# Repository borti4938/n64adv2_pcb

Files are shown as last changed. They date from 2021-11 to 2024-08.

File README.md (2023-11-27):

N64 Advanced 2 (PCB)
---

This repository contains all you need files to build your own DIY N64 Advanced board.
Firmware is supplied in another repository.

Please don't ask me for selling a modding.
I either sell some prototypes on some forums marketplaces (which is very unlikely) or I don't have any of the boards.
This is a complete DIY modding project.
Everybody is on his own here.

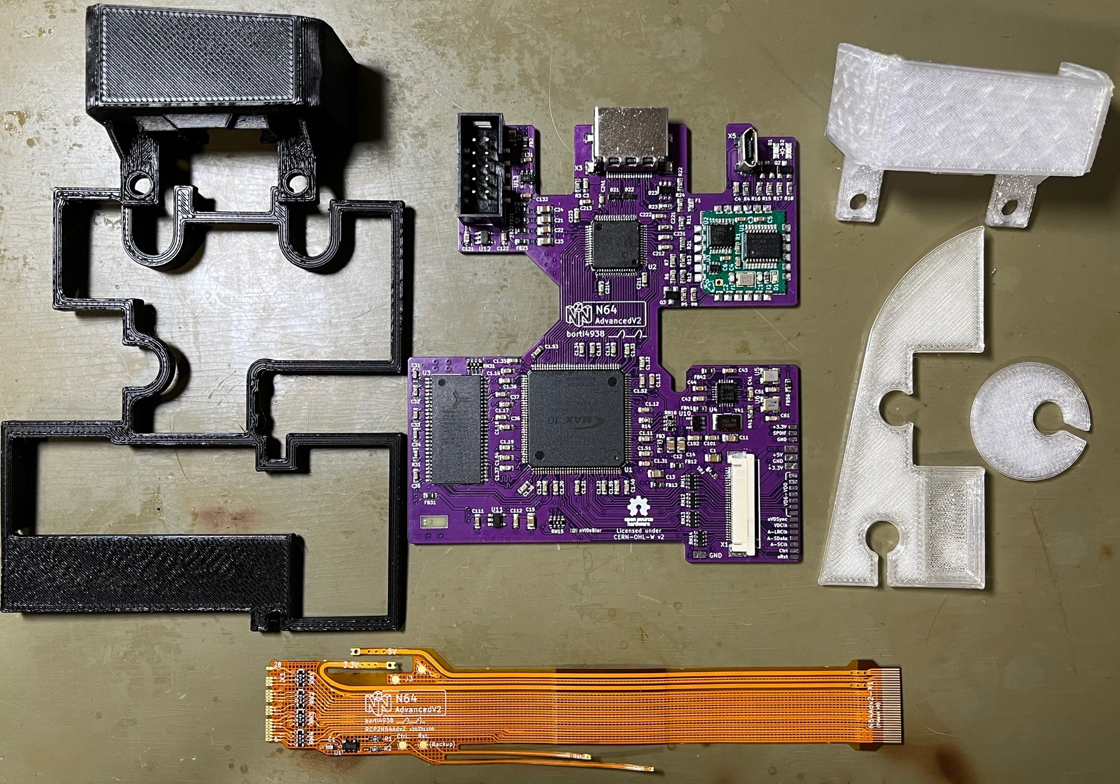
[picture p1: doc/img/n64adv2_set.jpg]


**WARNING:**
This is an advanced DIY project if you do everything on your own.
You need decent soldering skills.
The FPGA ad Video transmitter have 0.5mm fine pitch with 144pins and 64pins, respectively, and each has an exposed pad below the IC, which has to be soldered to the PCB.
Furthermore, the clocking chip is in a 24-QFN package where the pins are partwise below the IC.
It also has an exposed pad.
Next to it on the board there are some SMD1206 resistor and ferrite bead arrays.

One note on KiCad: please do not use version 7 and stay with version 6.xx.yy, if you want to edit the PCB.
I have to adapt the design files first before there are working as intended in version 7.
Thanks!

## Table of Contents

- [Checklist](https://github.com/borti4938/n64adv2_pcb#checklist-how-to-build-the-project)
- [Assembly](https://github.com/borti4938/n64adv2_pcb#assembly)
- [PCB Specs](https://github.com/borti4938/n64adv2_pcb#pcb-specs)
- [Installation](https://github.com/borti4938/n64adv2_pcb#installation)
  - [1. Open the Console](https://github.com/borti4938/n64adv2_pcb#1-open-the-console)
  - [2. Preparation](https://github.com/borti4938/n64adv2_pcb#2-preparation)
  - [3. Solder Work](https://github.com/borti4938/n64adv2_pcb#3-solder-work)
  - [4. Testing Installtion](https://github.com/borti4938/n64adv2_pcb#4-testing-installation)
  - [5. Put Everything Together](https://github.com/borti4938/n64adv2_pcb#5-put-everything-together)
- [Installation with UltraPIF](https://github.com/borti4938/n64adv2_pcb#installation-with-ultrapif)
- [Jumper Description](https://github.com/borti4938/n64adv2_pcb#jumper-description)

## Checklist: How to build the project

- Use PCB files to order your PCBs. You need the order the main PCB. If you plan to have a clean install, you need to order a flexible PCB, too. You can opt for a fully custom flex-PCB or a partial flex-PCB where you run a FFC cable from flex to main PCB. Important PCB specifications are provided in the [BOM](./doc/n64adv2_BOM.xlsx).
  - Main PCB: either [KiCAD-PCB design file](./pcbs/main/n64adv2.kicad_pcb) or [Gerber files](./gerber/main/)
  - Full Flex PCB: either [KiCAD-PCB design file](./pcbs/flex/rcp2n64adv2.kicad_pcb) or [Gerber files](./gerber/full_flex/)
  - Partial Flex PCB: either [EAGLE-PCB design file](./pcbs/flex/rcp2fpc_v5.brd) or [Gerber files](./gerber/part_flex/)
- If you plan to use solder paste, do not forget to order a stencil for top and bottom, too
- Source the components you need, e.g. from Mouser or Digikey.
  The BOM is available in [here](./doc/n64adv2_BOM.xlsx).
- If you want to use a assembly service (PCBA), you have to generate position files and BOM (in format as the fab requests it) out of the PCB design files. For JLCPCB e.g., there is a [KiCad plugin](https://github.com/Bouni/kicad-jlcpcb-tools) available (which I yet didn't test).
- Wait for everything to arrive
- Assemble your PCB if you haven't use a PCBA service
- Flash the firmware ([firmware releases](https://github.com/borti4938/n64adv2_fw/releases)) after installing:
  - Use the POF programming file named n64adv2\__fpga-device_.pof
  - Using the intelFPGA programmer, JTAG chain is initialized by loading POF file
  - Select CFM0 and UFM for program and verify
  - N64 needs to be powered for flashing
  - Power cycle the N64 after flashing

## PCB Specs

- **Main-PCB** Use PCB files (either [KiCAD-PCB design file](./pcbs/main/n64adv2.kicad_pcb) or [Gerber files](./gerber/main/)) to order your own PCB with following specs (might be not comprehensive)  
  - Size: 89.6mm x 80.0mm
  - Layer: 4
  - FPC thickness: 1.6mm
  - Min hole size: dia 0.3mm / ring 0.6mm or lower
  - Min trace width / spacing: 0.2mm
- **Flex-PCB** Use PCB files (either [KiCAD-PCB design file](./pcbs/flex/rcp2n64adv2.kicad_pcb) or [Gerber files](./gerber/full_flex/)) to order your own PCB with following specs (might be not comprehensive)  
  - Size: 129.6mm x 25.0mm
  - Layer: 2
  - FPC thickness: 0.15mm \[1\]
  - Min hole size: dia 0.25mm / ring 0.45mm or lower
  - Min trace width / spacing: 0.2mm
  - Stiffener: PI top + bottom
  - Stiffener thickness: 0.15mm \[1\]

\[1\] You may have to vary FPC thickness and stiffener thickness depending on the prototype service you are going with. E.g., on my last order I opted for 0.12mm PCB thickness and 0.225mm polyimide thickness.

## Assembly

If you have all components available, you can start assembly your board.
You can use the [interactive BOM](./doc/n64adv2_main_ibom.html), which helps you organizing your work.
It is just a matter of time and effort to assembly everything.

Note that the FPGA has an exposed pad, which needs a good connection.
Otherwise, the FPGA will not boot at all.
Preheat the FPGA with a hot air gun and solder the exposed pad from bottom if you do not use solder paste.
If you only have your solder iron, apply heat from bottom.
You must be patient at this point as there are large GND planes around the FPGA.
You may check the FPGA temperature with your finger on the top side (once it gets too hot to touch, you may stop for soldering for a moment).
Do the same with the other chips which have an exposed pad (U2 and U4).

If you populate X2 with the THT variant, which is the JTAG connector, please short the pins such that they are flush at the bottom side.
Otherwise, the PCB might be lifted in its position which produces unnecessary mechanical stress on PCB and HDMI connector.

Using non-clean flux (rosin based) is obviously recommended.
Even though it is "non-clean" I recommend cleaning everything afterwards (just for the visual finish).

Please double check everything for shorts once you finished your work.
Very important is that the power supply trace do not short to GND.
- 5V against GND (e.g. at input pads)
- 3.3V against GND (e.g. at input pads)
- 2.5V against GND (e.g. at C14)
- 2.5V against GND (e.g. at C15)
- 3.3V against GND (e.g. at C132)
- 1.8V against GND (e.g. at C122)

## Installation

### 1. Open the console

- Remove Jumper Pak / Expansion Pak
- Remove screws from bottom side of the console  
(needs a 4.5mm gamebit tool)
- Lift top housing
- remove inner screws as marked  
(in very last consoles made the heat sink design changed slightly)
- pull out the mainboard
- remove heat sink and RF shield
- **Hint** Now you have the chance to clean up your N64 shell

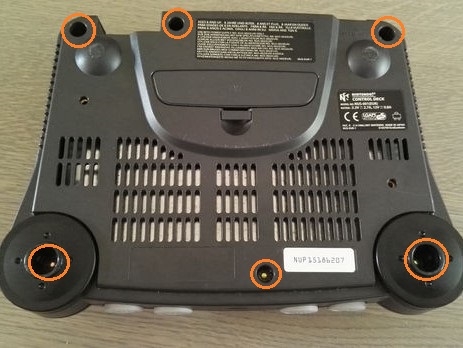
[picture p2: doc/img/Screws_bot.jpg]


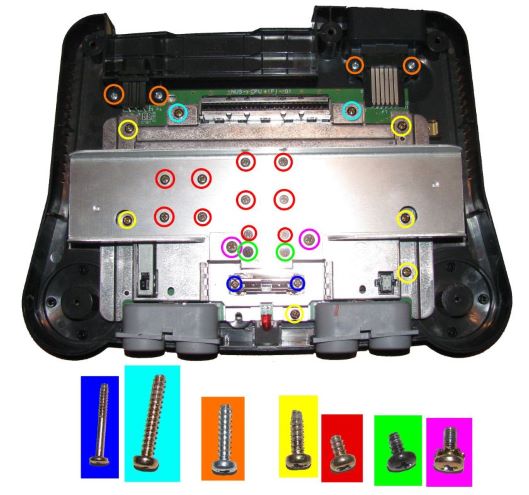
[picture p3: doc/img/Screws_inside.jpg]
  
(image by Zerberus (circuit-board.de user))

### 2. Preparation

It is possible to do a cut or a no-cut installation.
You will need the following parts for it:

1. N64Adv2 PCB
2. Flex Cable
3. Two to four of washers (M3)
4. Thermal pad
  - Cut Mod: appr. 1mm to 1.5mm thickness
  - No Cut Mod: appr. 2.5mm to 3.0mm thickness
5. 3D printed parts:
  - Cut Mod: [USB port round filler](./prints_3d/HalfCut/N64Adv2_USB_RoundFiller.stl), [JTAG spacer](./prints_3d/HalfCut/N64Adv2_JTAG_Spacer.stl) and [MultiOut replacement](./prints_3d/HalfCut/N64Adv2_MultiOut_HalfCut.stl)
  - No Cut Mod: [PCB lift bracket](./prints_3d/NoCut/N64Adv2_PCB_lift.stl) and [MultiOut replacement](./prints_3d/NoCut/N64Adv2_MultiOut_NoCut.stl)

#### 2.1 Shell Preparation Cut Mod

The bottom shell needs a cutout at the MultiOut port.

Mark the place you need to file with either the N64Adv2 PCB or the 3D printed MultiOut replacement.



File down the shell within your markings until the N64Adv2 sits flush on the shell floor.
Consider a tiny space below the HDMI connector.
Cleanup the shell and place the 3D printed parts into the shell.
Make a final fit test as shown.



#### 2.2 Shell Preparation No Cut

There is no need to cut the shell at all with this variant.
All you need is to remove the bottom RF shield from the N64 mainboard.

Place all 3D printed parts and make a fitting test as shown.



### 3. Solder Work

You have the options to either install everything with casual installation wires or using flex cables.
This is just a trade-off between personal installation effort and price.
Personally, I recommend using the flex cable.
Also with the flex cable you have the option to use a fully custom flex or a partial flex which just have a FFC connector on it to run a FFC cable from N64 to N64Adv2.

The instruction shows the installation with the fully custom flex.
The partial flex installation is similar, but not shown here.
The wired installation is not shown and not documented at all! (at least for the moment)

#### 3.1 Prepare the Flex Cable

The flex cable will be routed through the RF shield.
Close to it there are some capacitors.
Gently bend the flex cable between resistors and protection area (stiffener at top and bottom) as shown.
This relaxes routing with as low stress on the flex cable as possible.

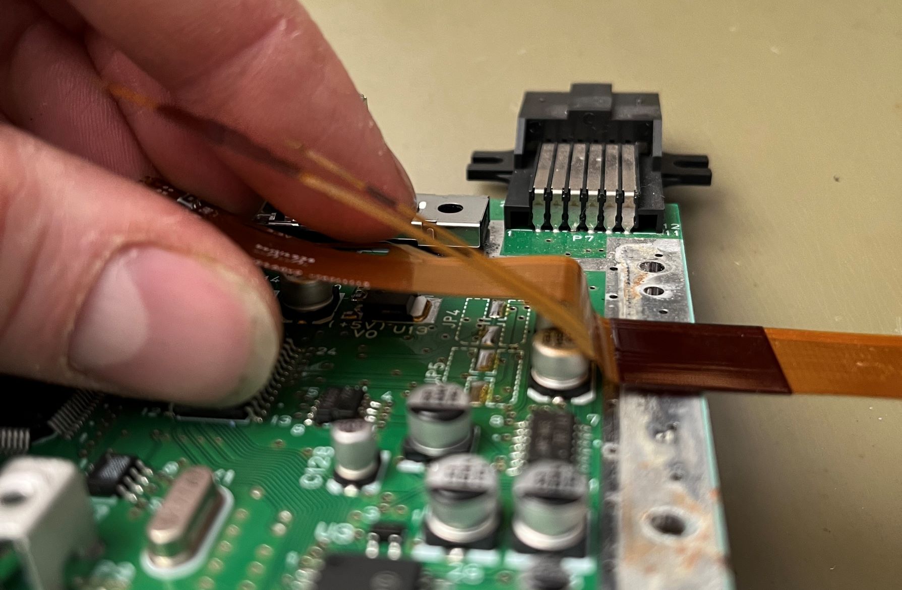
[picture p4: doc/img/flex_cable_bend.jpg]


If you opt for the partial flex, postpone this step until you have the partial flex installed (after step 3.2).
Measure where the FFC cable needs to be bend.
Apply some insulation tape for cable protection behind the bending area.

#### 3.2 Flex Cable Installation

Place the flex cable to the RCP-NUS output pins 6 to 28 as shown.
Put the solder area on to of the pins.
(However, putting them in front is also possible.)

Secure the cable with some kapton tape or with two solder joints.
Make sure that solder pads and pins are perfectly aligned.
The better the alignment is the easier is the solder work.

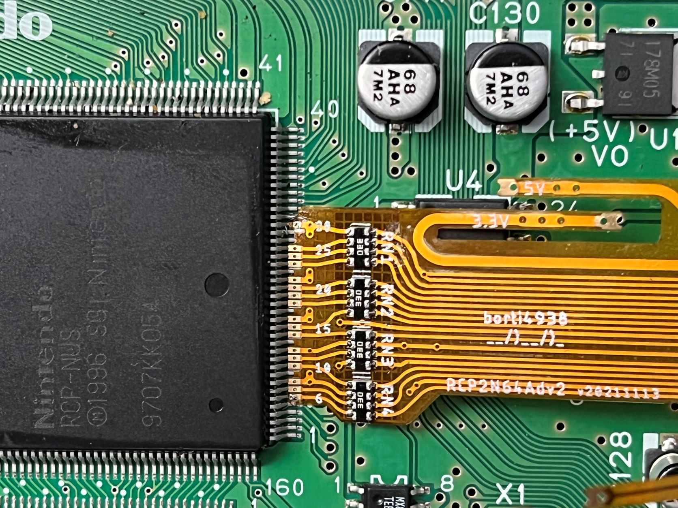
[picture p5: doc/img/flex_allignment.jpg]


Apply solder to all pins.
Double check for shorts and good connections with a continuity tester of a digital multimeter.

Solder 3.3V, 5V, Reset and Controller legs to the N64 as shown.

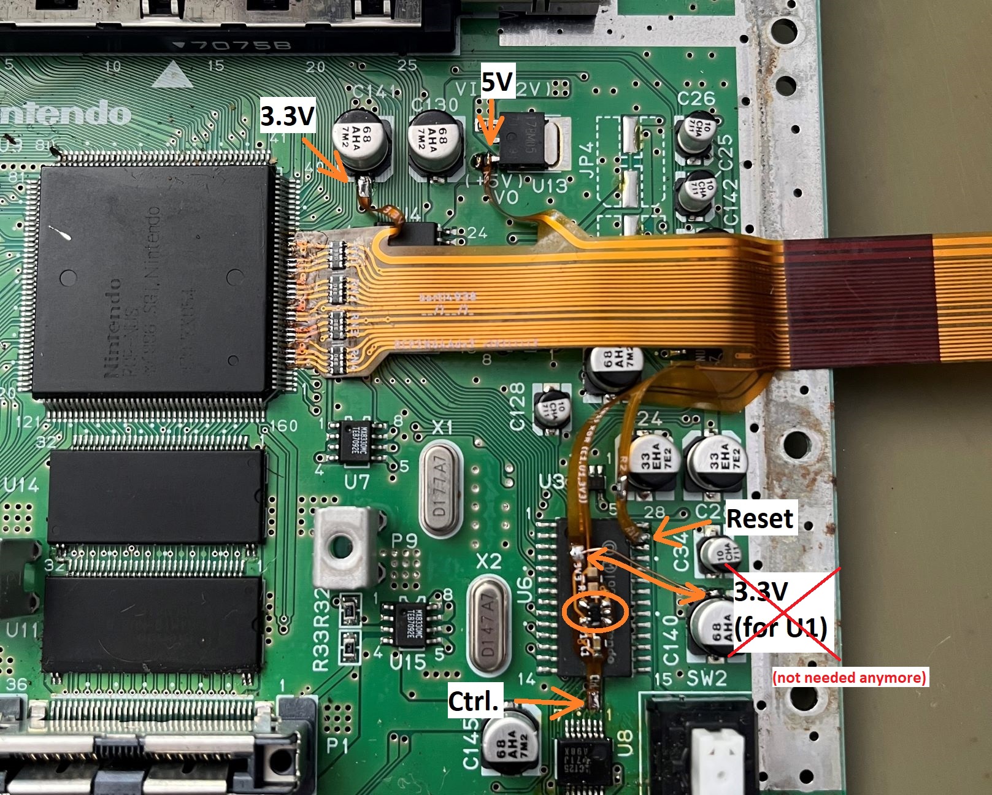
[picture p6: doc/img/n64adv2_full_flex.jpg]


Short summary:
- Solder the RCP connector side to the RCP-NUS as shown
  - first pin bottom – 6
  - last pin to – 28
- Connect 3.3V to the flex, e.g. taken from C141
- Connect 5V to the flex, e.g. taken from U13
- Connect Ctrl. and reset
  - reset from PIF-NUS pin 27
  - Controller from PIF-NUS pin 16  
  (Make sure that PIF-NUS pin 16 is connected to the middle pin of controller port 1, otherwise search for a suitable connection point)
- If you have a CPLD-based RGB mod, you can use J3 to setup VI-DeBlur on that mod over the N64Adv2
  - J3 has two pads: the left one (directly above the N64Adv2 logo) is the feedback signal, the other one is GND.
    Use a DMM if you are unsure (the GND pad has connection to any GND point on the N64 mainboard if flex is installed)
  - J3 signal pad is high on VI-DeBlur disabled and goes low if enabled

#### 3.2a Flex Cable Version 20231105 (and later)

With Version 20231105 the flex cable was redesigned at the ends to controller and reset connection at the PIF-NUS.

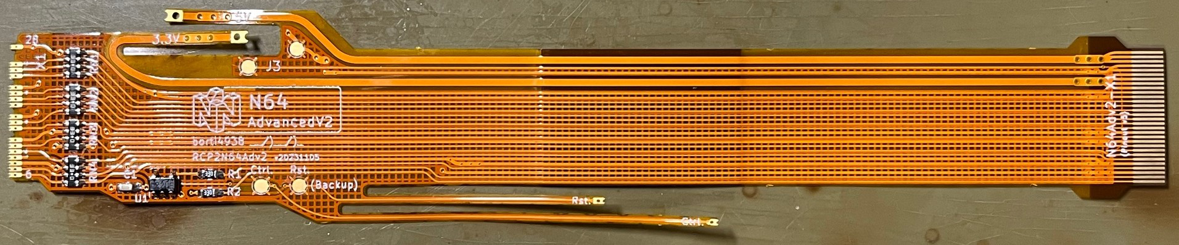
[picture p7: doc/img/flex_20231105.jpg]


Changes were:
- No components anymore on the thin cable ends for easier handling
- Using a single gate buffer (U1) for the controller line is now mandatory.
- Backup pads for controller and reset connection of the thin cable breaks.
  If cable breaks you can simply cut off the broken cable end and route a separate wire from PIF pin to the backup pad.

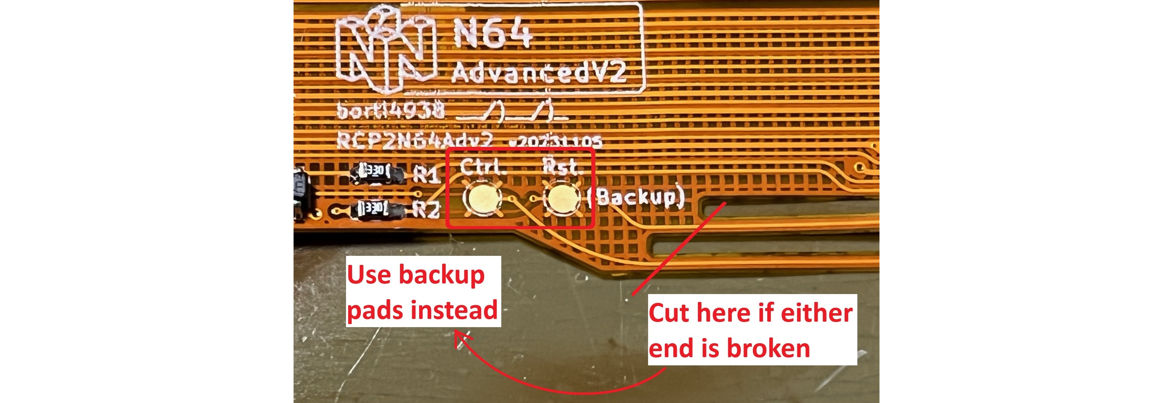
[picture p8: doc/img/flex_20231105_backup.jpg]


#### 4. Testing Installation

At this point it is a good idea to test your installtion.

First you should check for some obvious short at the power rails, e.g. between 3.3V and GND, and between 5V and GND.
If the N64Adv2 board is connected with the flex, you can simply use the input pads on the N64Adv2 board.

Insert a game cartridge, connect HDMI and power, and turn on your N64!
**Important:** If you do not have heatsinks attached to your N64, only test for a brief moment.

Obviously, the firmware of the N64Adv2 must be flashed to the FPGA.

If you see a picture with game output and here some game audio, then everything might be ok.
It's a good idea to run the debug-screen for a quick check.
If something is not ok, the N64Adv2 hardware should boot into the debug screen by default.
Then you have to go for debugging your installation.

Additional information on flashing the firmware and how to debug with the debug screen, can be found the [firmwares repository](https://github.com/borti4938/n64adv2_fw).

#### 5. Put Everything Together

Secure your installation from shorts to the top RF shield with some insulation tape.
There is a risk for shorts where the controller leg of the full flex is routed.
Everything else is safe.

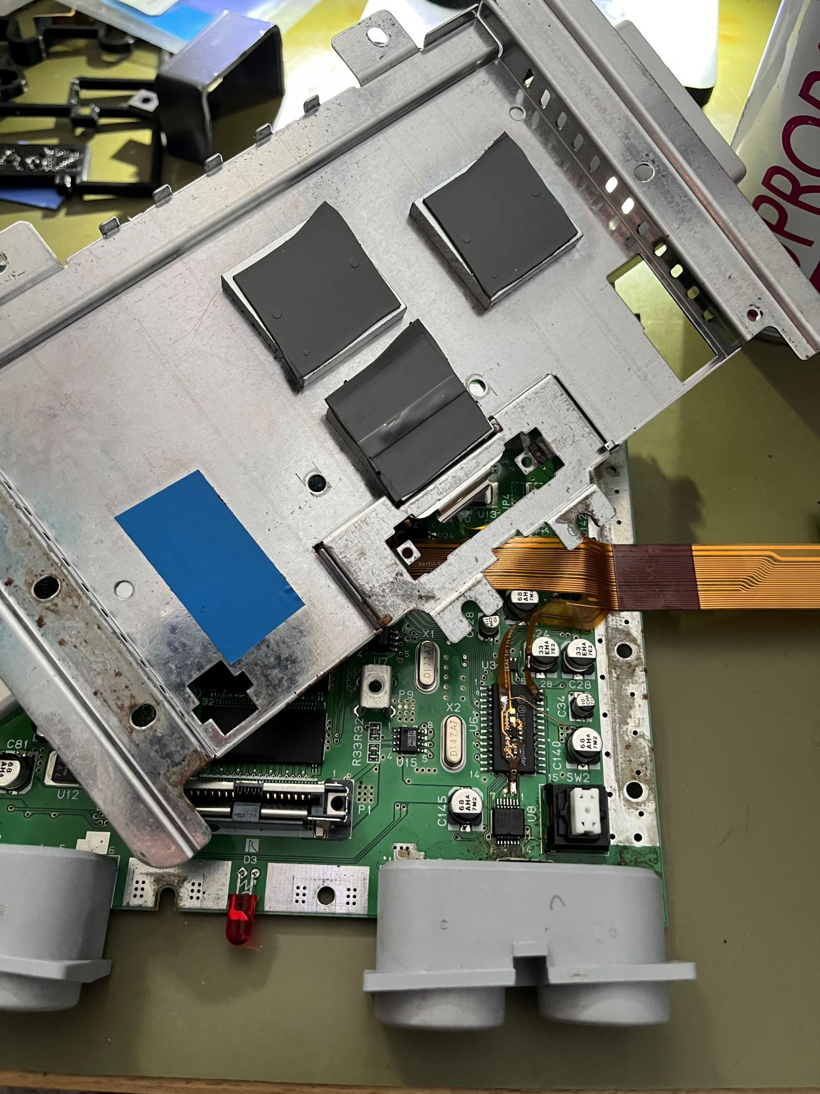
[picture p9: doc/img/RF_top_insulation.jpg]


Place some washer (about 0.5mm to 1mm height) at the screw spots left and right of the N64Adv2 flex cable.
From my experience it is easier to secure them with some tape.
Close the RF shield of the N64 then.

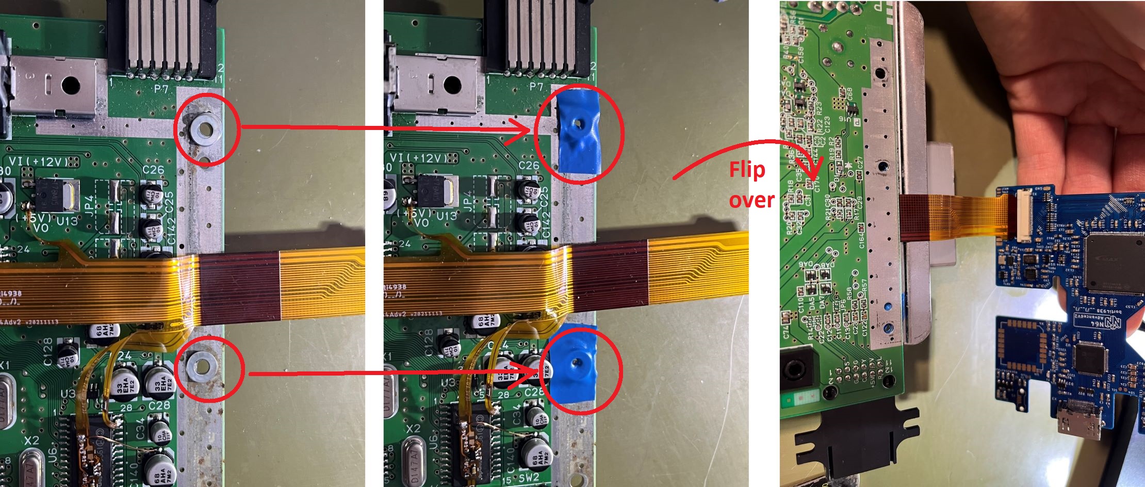
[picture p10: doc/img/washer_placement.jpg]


Now connect the N64Adv2 PCB to the flex cable.
For the Cut-Mod, also place the bottom RF shield into its place of the N64.
The RF shield does not fit in the no-cut mod variant.

Put the thermal pad on top of the FPGA (U1) of the N64Adv2 board.
This helps with heat dissipation and holds the PCB in its place.

Put everything in the bottom shell.
Do not forget 3D printings.

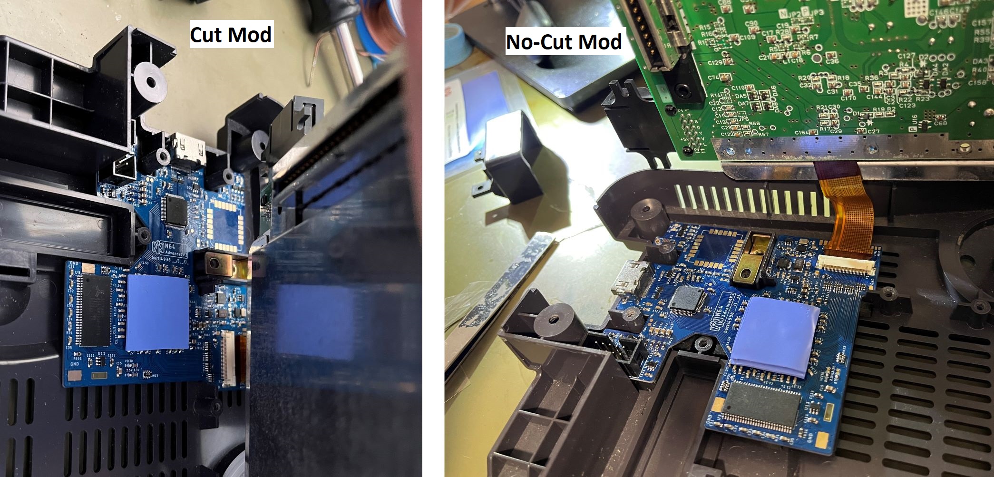
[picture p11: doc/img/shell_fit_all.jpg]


Secure the N64 with two or three screws and make a small test to see if everything is working.
Do not forget to put in the Jumper Pak or Expansion Pak, otherwise you won't see a picture at all.

If everything works fine, close the whole shell.

## Installation with UltraPIF

This guide assumes that the UltraPIF will be installed after the N64Adv2.
However, other installation orders are possible, too - i.e. UltraPIF first and then N64Adv2 or both alongside.
There are not described, here.
For the ease of debugging, installation one after the other is always recommended.

Also, it is not described, how to open and close the N64.

### 1. Remove PIF-NUS

To remove the PIF-NUS, remove reset and controller connections, first.

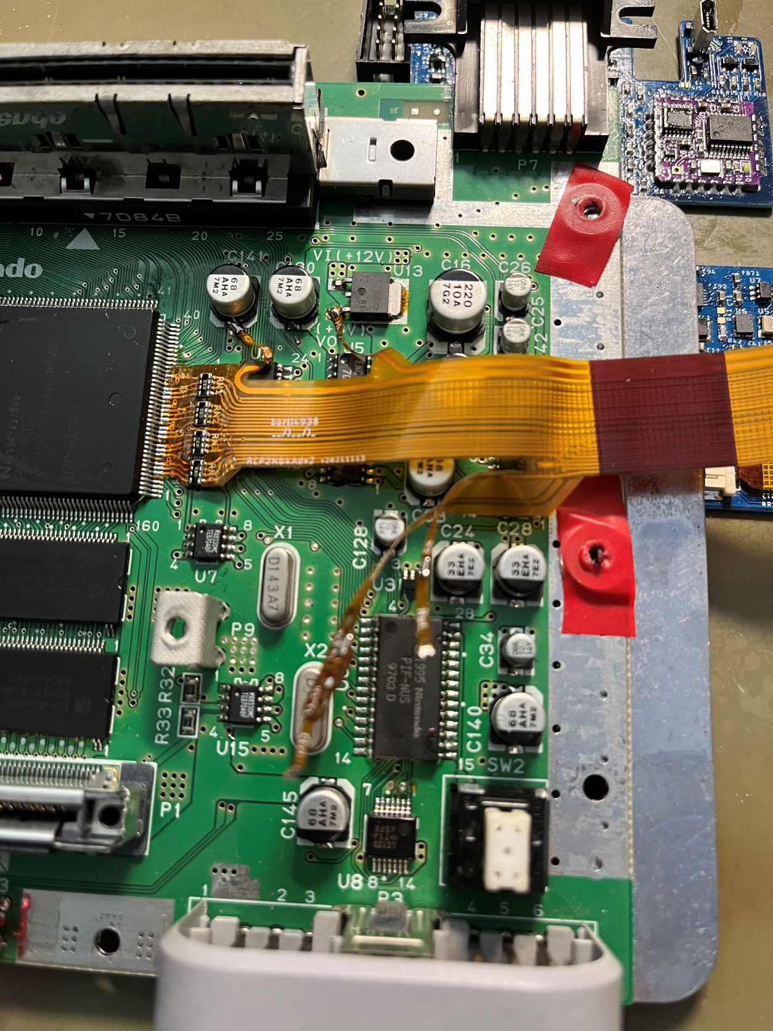
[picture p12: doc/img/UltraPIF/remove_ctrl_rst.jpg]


The remove the PIF-NUS.

### 2. Install UltraPIF Adapter Board

Put the UltraPIF board into its place.
Connect clock and mode wires and if you want, the RGB led board.
More details on that can be found in the [UltraPIF Repository](https://github.com/jago85/UltraPIF_Hardware/wiki/Installation).

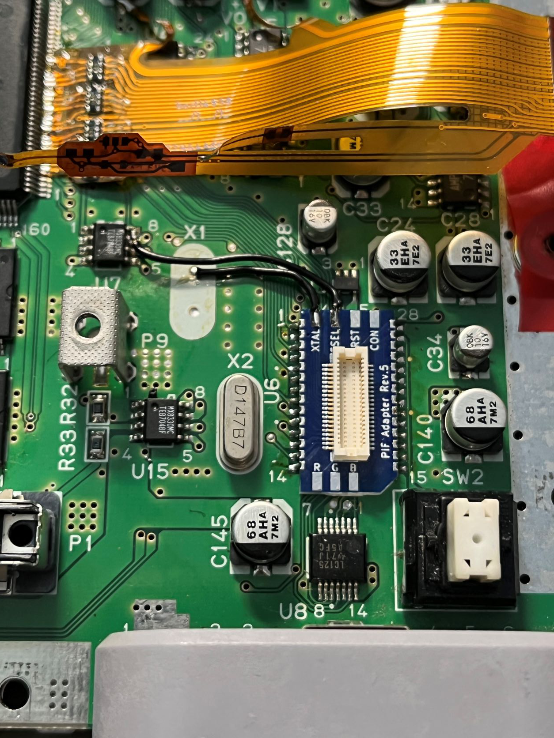
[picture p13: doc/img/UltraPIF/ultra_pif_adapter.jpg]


### 3. Connect Flex Cable

Once the UltraPIF Adapter sits in its place, you can reconnect the reset and controller connections of the flex cable.

For the controller connection, you can use the _CON_ pad on the adapter.

For the reset connection you have to go for pin 27 on the adapter.
**DO NOT USE THE _RST_ PAD!** as it acts as an input only.
Fallback functions won't be available if you do so.
Check the connection for shorts to adjacent pins.

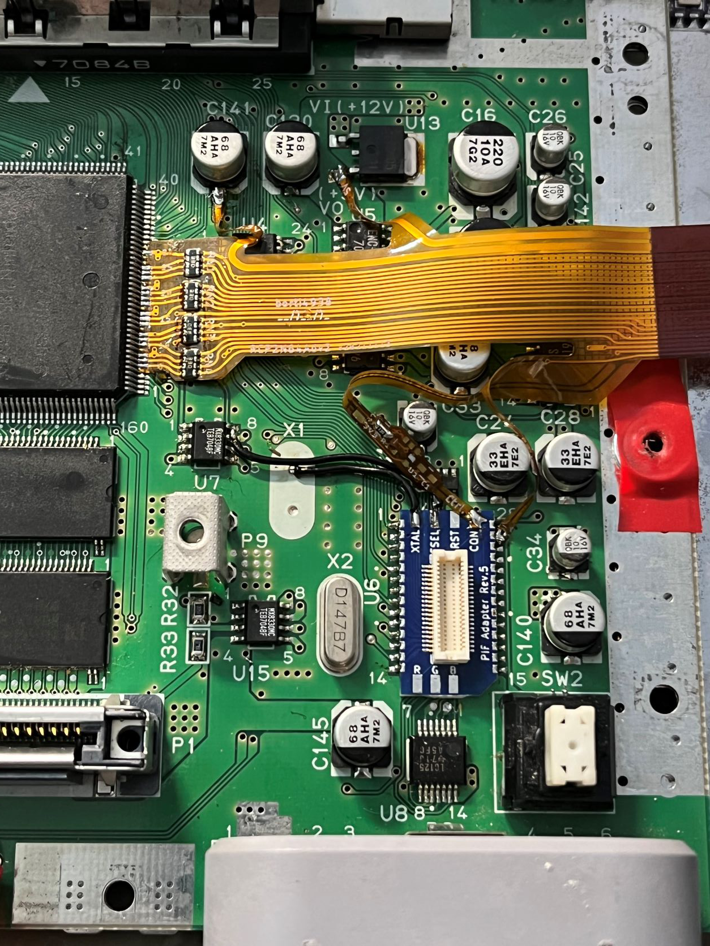
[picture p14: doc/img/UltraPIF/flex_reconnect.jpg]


### 4. Done

Put the UltraPIF on the UltraPIF Adapter board.

## Jumper Description

**IMPORTANT NOTE**  
Most jumpers are for development reasons and do not need to be touched at all.
This section is only for documentation purposes.

### On main N64Adv2 PCB

##### SJ1 to SJ4 (IO power supply for FPGA Bank 6 and 7)

**Section is outdated. Jumpers had been removed with version 20231119**

Bank B6 and B7 needs 2.5V VCCIO for current implementation.
Since N64Adv2_202200415, these jumpers are closed by default at 2.5V.
Earlier prototypes need a solder joint at 2.5V.
Do not touch 3.3V jumper as current implementation runs IO speed over specifications then.

##### SJ5 (5V power via USB port (X5))

**Section is outdated. Jumper has been removed with version 20231119**

- opened: (default) disable 5V power via USB
- closed: enable 5V power via USB

##### SJ6 (3.3V power via JTAG programmer X4)

**Section is outdated. Jumper has been removed with version 20231119**

- opened: (default) disable 3.3V power via JTAG programmer
- closed: enable 3.3V power via JTAG programmer

#### SJ11 (VI-DeBlur feedback)
- opened: disable feedback for fir flex prototypes
- closed: (default by a trace) feedback enabled

##### SJ31 (SRAM A12)

**Section is outdated. Jumper has been removed with version 20231119**

- opened: (default) use 8Mx16 memory
- closed: use 16Mx16 memory (firmware needs adaptation to work with 16Mx16 memory)

### On flex PCB

##### SJ1

**Section is outdated. Jumpers had been removed with version 20231105**

- opened: use with Schmitt trigger buffer (U1 and C1)
- closed: close jumper if you do not use Schmitt trigger buffer (U1 and C1)

##### J3
- VI-DeBlur feedback for CPLD based RGB mods (see installation section)

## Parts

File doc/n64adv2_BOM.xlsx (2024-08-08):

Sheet: Main
Number of PCBs |  | 3
Designator | MPN | QTY/PCB | QTY | DESCRIPTION | VALUE | PACKAGE | NOTES | Digikey | Mouser
U1 | 10M16SAE144 | 1 | 3 | Max10 FPGA, 16k LE |  | EQFP144 | For user
 | 10M25SAE144 |  |  | Max10 FPGA, 25k LE |  | EQFP144 | For developer or as user alternative (more FPGA resources)
U2 | ADV7513BSWZ | 1 | 3 | HDMI Transmitter | ADV7513 | 48-LQFP | Aliexpress
U3 | AS4C8M16SA-xTCN | 1 | 3 | SDRAM Speicher-IC 128 Mb (8 M x 16) Parallel |  | TSOP-54 | x = Speedgrade (6 = 166MHz, 7 = 143MHz)
U4 | SI5356A-B-GMR | 1 | 3 | Clock generator |  | QFN-24
U5 | ECS-3225MV-500-CN-TR | 1 | 3 | OSC 50MHz for system pll |  | 4-SMD | L x B: 0,126" x 0,098" (3,20 mm x 2,50 mm)
U6 | ECS-3225MVLC-245.7-CN-TR | 1 | 3 | OSC 24.576MHz for audio |  | 4-SMD | L x B: 0,126" x 0,098" (3,20 mm x 2,50 mm)
U10 | TLV70225DBVR | 1 | 3 | LDO 2.5V, 300mA |  | SOT-23-5
U11 | TLV70025DDCR | 1 | 3 | LDO 2.5V, 200mA |  | SOT-23-5 | same as U10 can be used (but not vice versa)
 | TLV70225DBVR |  |  | Alternative for U11 (same as U10) |  | SOT-23-5
U12 | TLV70218DBVR | 1 | 3 | LDO 1.8V |  | SOT-23-5
U13 | TLV70033DDCR | 1 | 3 | LDO 3.3V |  | SOT-23-5
Y41 | 445I23D27M00000 | 1 | 3 | 27MHz crystal |  | 5.0X3.2
FB1,FB2,FB11,FB12,FB13,FB21,FB22,FB23,FB24,FB31,FB41,FB42,FB56 | MPZ1608S221A | 13 | 39 | Ferrit bead, power line |  | SMD0603
C1,C2 | ‎GRT21BR60J476ME13L‎ | 2 | 6 | Ceramic capacitor, X5R | 47uF / 6.3V | SMD0805
C11,C12,C13,C14,C15,C21,C22,C23,C24 | ‎CL21A106KPFNNNG‎ | 9 | 27 | Ceramic capacitor, X5R | 10uF / 6.3V | SMD0805
C101,C102,C111,C112,C121,C122,C131,C132 | ‎CL10A105KP8NNWC‎ | 8 | 24 | Ceramic capacitor, X5R | 1uF / 6.3V | SMD0603
C1.11,C1.12,C1.13,C1.14,C1.15,C1.16,C1.17,C1.18,C1.19,C1.20,C1.21,C1.22,C1.31,C1.32,C1.33,C1.34,C1.35,C1.36,C1.37,C1.38,C1.39,C1.40,C1.51,C1.52,C1.53,C1.54,C1.55,C3,C31,C32,C33,C34,C35,C36,C37,C41,C42,C43,C44,C211,C212,C213,C214,C221,C222,C223,C231,C241 | CL10B104KB8NNNL | 48 | 144 | Ceramic capacitor, X7R | 0.1uF / 50V | SMD0603
C51,C61 | CL10B103KB8NNNC | 2 | 6 | Ceramic capacitor, X7R | 0.01uF / 50V | SMD0603
R3 | RC0603FR-071ML | 1 | 3 | Resistor | 1M | SMD0603
R12,R13,R22 | RC0603FR-0710KL | 3 | 9 | Resistor | 10k | SMD0603
R23,R24 | RC0603FR-072KL | 2 | 6 | Resistor | 2k0 | SMD0603
R11,R15,R17,R31,R41 | RC0603FR-071KL | 5 | 15 | Resistor | 1k0 | SMD0603
R21 | RC0603FR-07887RL | 1 | 3 | Resistor | 887 | SMD0603
R16,R18 | RC0603FR-07330RL | 2 | 6 | Resistor | 330 | SMD0603
R14 | RC0603FR-0733RL | 1 | 3 | Resistor | 33 | SMD0603
RN11,RN12,RN13,RN14 | BLA31AG121SN4D | 4 | 12 | Ferrite Beads MULTILYR CHP | BD 120OHMS 25% | SMD1206
RN15,RN31 | CAY16-103J4LF | 2 | 6 | Resistor Array (4x) | 10k0 | SMD1206
RN16 | CAY16-2201F4LF | 1 | 3 | Resistor Array (4x) | 2k2 | SMD1206
F1 | MF-FSMF020X-2 | 1 | 3 | 200mA Fuse |  | SMD0603
D1 | LTST-C194KRKT | 1 | 3 | Red LED |  | SMD0805
D2 | LTST-C194KGKT | 1 | 3 | Green LED |  | SMD0805
 | LTST-C194KRKT |  |  | Alternative for D2 (same as D1) |  | SMD0805
D21,D22 | RCLAMP0524PATCT | 2 | 6 | TVS Diode |  | 10-UFDFN
 | SZESD7104MUTAG |  |  | TVS Diode |  | 10-UFDFN | Alternative
D23 | NUP4114HMR6T1G | 1 | 3 | Clamping Diode Array |  | TSOP-6
Q1,Q2 | ZXTN08400BFFTA | 2 | 6 | NPN-Transistor |  | SOT-23
X1 | 3-1734592-0 | 1 | 3 | contacts bottom, cable 0.3mm thick (flex + stiffener) |  |  | 30 pin 0.5mm flat cable connector, reverse v5 pinout, 5V & 3.3V power rail, GND and data
 |  |  |  |  |  |  | only in combination with flex (see separate tab)
X2 | 3020-10-0300-00 | 1 | 3 |  |  |  | JTAG Connector (2x5 pins in 100mil pitch; SMD)
 | 30310-6002HB |  |  | Alternative for X2 as THT, but need to short pins |  |  | JTAG Connector (2x5 pins in 100mil pitch; THT)
 |  |  |  |  |  |  | optional if onboard USB Blaster is used (see separate tab)
X3 | 2000-1-2-41-00-BK | 1 | 3 | HDMI Connector 19pin with SMD mounted shield |  |  | Full Size HDMI Connector
X4 | Onboard USB Blaster |  |  |  |  |  | see Onboard USB Blaster page

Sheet: Onboard USB Blaster
Number of PCBs |  | 3
Designator | MPN | QTY/PCB | QTY | DESCRIPTION | VALUE | PACKAGE | NOTES | Digikey | Mouser
X4 | TEI0005 | 1 | 3 | FPGA USB-Programmer2 SMD-Modul |  |  | Buy: https://shop.trenz-electronic.de/de/TEI0005-02-FPGA-USB-Programmer2-SMD-Modul-VPE1?c=26
 |  |  |  |  |  |  | Wiki: https://wiki.trenz-electronic.de/display/PD/TEI0005+-+FPGA+Programmer2+SMD
 | DIY |  |  | DIY USB Blaster module project |  |  | Thx to ikari_01 (creator sd2snes / fxpak)
X5 | USB3140-30-0170-0-C | 1 | 3 | USB-MICRO-VERTICAL-DIY
C4 |  | 1 | 3 | Ceramic capacitor, X7R | 0.1uF / 50V | SMD0603
R4 | RC0603FR-071ML | 1 | 3 | Resistor | 1M | SMD0603
R5,R8 | RC0603FR-0710KL | 2 | 6 | Resistor | 10k | SMD0603
R6,R7 |  | 2 | 6 | Resistor | 1k0 | SMD0603 | 1k to 5k
Q3 | ZXTN08400BFFTA | 1 | 3 | NPN-Transistor |  | SOT-23

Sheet: Flex
Number of PCBs |  | 3
Designator | MPN | QTY/PCB | QTY | DESCRIPTION | VALUE | PACKAGE | NOTES | Digikey | Mouser
U1 | 74LVC1G17DBV | 1 | 3 | Schmitt-Trigger Buffer |  | SOT-23-5
C1 | CL10B104KB8NNNL | 1 | 3 | Ceramic capacitor, X7R | 0.1uF / 50V | SMD0603
RN1,RN2,RN3,RN4 | CAY16-330J4LF | 4 | 12 | Resistor Array (4x) | 33ohm | SMD1206
R1,R2 | RC0603FR-0733RL | 2 | 6 | Resistor | 33ohm | SMD0603

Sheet: Jumper
Testpads | Description
SPDIF | SPDIF output, e.g. for optical audio link
+3.3V, +5V, GND | Power connection (for SPDIF, testing, whatever)
VD0 - VD6, nVDSync, VDClk, A-LRClk, A-Sdata, A-SClk, Ctrl, nRst | Pads to connect the N64Adv2 mainboard without the flex cable
 | Usefull for debugging if N64Adv2 is not working after installation with flex
Jumper on Flex | Description
J3 | Feedback signal from N64Adv2 for VI-DeBlur setting
Ctrl. (Backup) | Backup pad to route a wire from PIF to flex if trace end on flex is broken
Rst. (Backup) | Backup pad to route a wire from PIF to flex if trace end on flex is broken

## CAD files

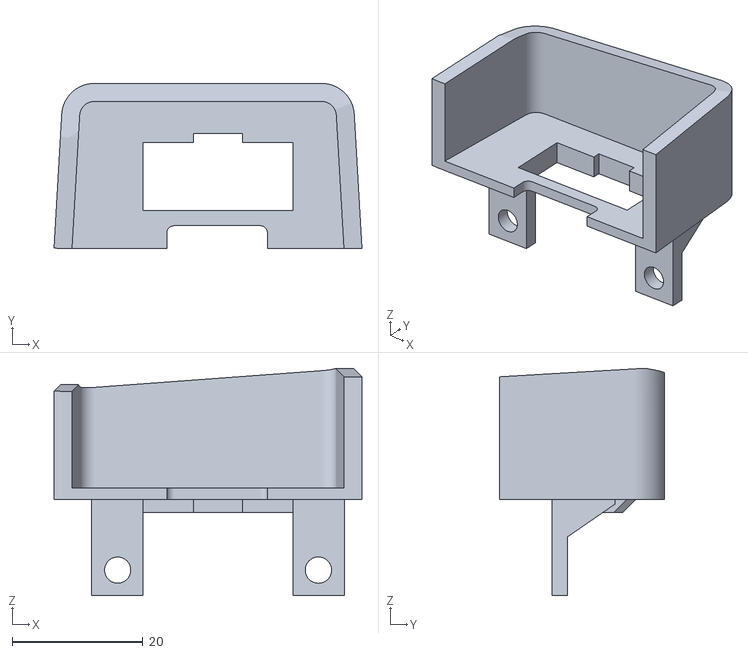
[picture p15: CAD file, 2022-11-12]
prints_3d/HalfCut/N64Adv2_MultiOut_HalfCut.stl
47.1 x 25.3 x 34.8

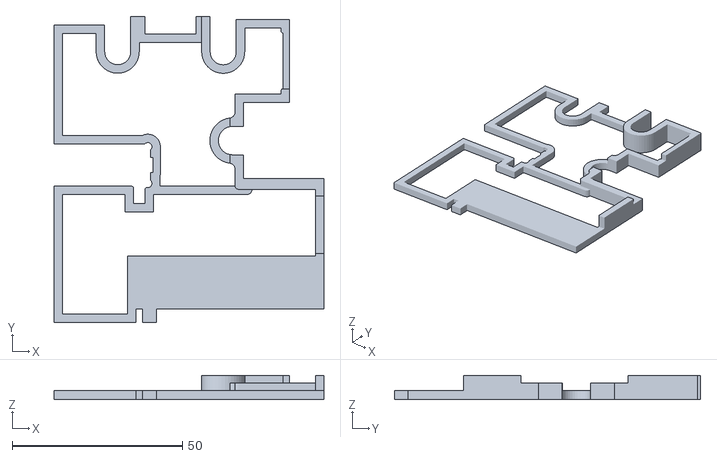
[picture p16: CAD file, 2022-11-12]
prints_3d/NoCut/N64Adv2_PCB_lift.stl
79.1 x 89.8 x 7.11

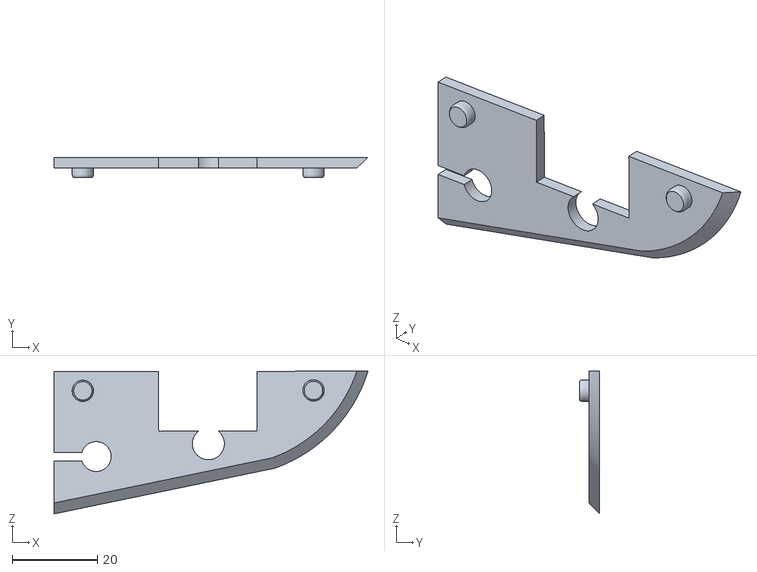
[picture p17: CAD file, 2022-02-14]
prints_3d/HalfCut/N64Adv2_JTAG_Spacer.stl
73.5 x 4.75 x 33.4

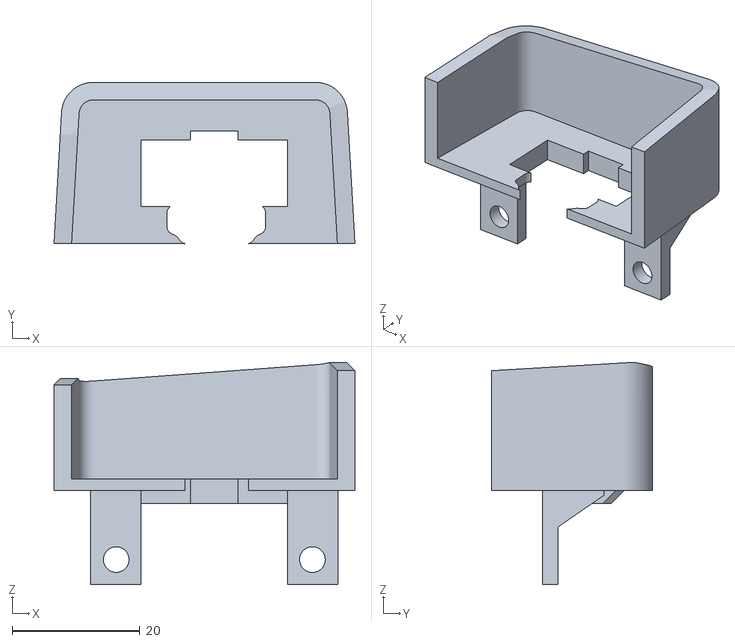
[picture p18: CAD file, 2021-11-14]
prints_3d/NoCut/N64Adv2_MultiOut_NoCut.stl
47.1 x 25.3 x 34.8

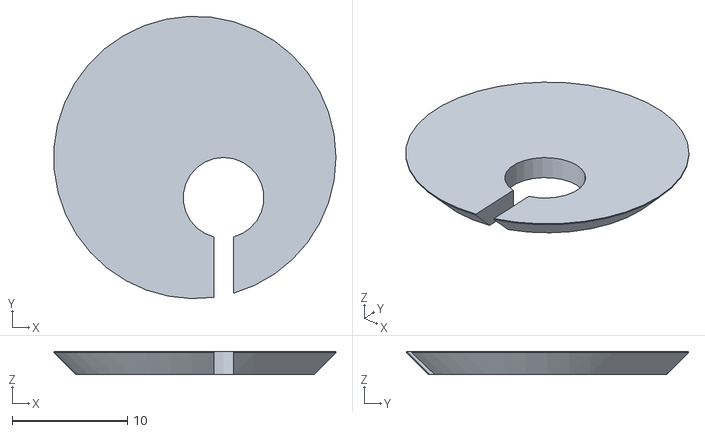
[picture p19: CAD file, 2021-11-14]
prints_3d/HalfCut/N64Adv2_USB_RoundFiller.stl
24.5 x 24.5 x 2.00

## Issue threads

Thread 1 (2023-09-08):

PCB mounting files

nrayner, 2023-09-08:
In the readme it says:

If you want to use a assembly service (PCBA), you can use the mounting files for [main](https://github.com/borti4938/n64adv2_pcb/blob/master/doc/n64adv2-top-pos.csv), full flex-PCB and/or part flex-PCB, too.

But the link doesn't work, I could not find the files anywhere else in the repository.

borti4938, 2023-09-08:
Sorry. I removed the file as it was not working for any fab. At the moment you have to generate your own files in a format as requested by the fab of your choice. Maybe we will add some example files for JLCPCB in near future.

nrayner, 2023-09-08:
Ok thanks

Closed 2024-08-25.

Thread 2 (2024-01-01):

Alternativ FPGA?

cerritus55, 2024-01-01:
Is there any alternativ for the FPGA thats still aviable and working with this project?

borti4938, 2024-01-04:
New FPGA needs a redesign of PCB and firmware. Everything is open source, so feel free to make your adaptations. Or just be patient - FPGAs will be available soon. Estimated delivery date at Digikey is 01/17/2024 if you order today.

Closed 2024-01-04.

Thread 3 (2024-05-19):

Interference

Slypty, 2024-05-19:
I've made a set of 8 N64Adv2 boards with PCBWay, received them and doing some testing.  2 of the 8 boards test well, the other 6 all have blue pixels that appear.  The pixels will go away if I press down between the FPGA MAX 10 and the Alliance IC as shown below.  I have tried touching up solder joints in this area but no differences were made.

  If I add thermal tape to the underside of the PCB it gets better.  Eventually the pixels go away after many minutes.  6 boards all have this issue, I am wondering if I should replace the caps in this area, or maybe if this is a noisy 3.3V line?  Is this a problem you're familiar with?   Hope you can help, thanks
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

Slypty, 2024-05-22:
Well it ended up being a faulty N64 Power Supply, so it can be deleted/closed.

borti4938, 2024-05-22:
Thanks for closing. I'm happy that you were able to track down the issue :)

Closed 2024-05-22.

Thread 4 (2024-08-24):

SDRAM alternative part

gmiranda, 2024-08-24:
Hi,

I'm having trouble sourcing the alliance SDRAM chip (AS4C8M16SA) and I'm looking into alternatives. I think this Winbond W9812G6KH ([datasheet](https://www.lcsc.com/datasheet/lcsc_datasheet_2304140030_Winbond-Elec-W9812G6KH-6_C62379.pdf)) would work but I'm not sure.

Could you please have a look or suggest another IC?

Thanks!

borti4938, 2024-08-25:
Hi,

the AS4C8M16SA-7TCN is available on Digikey and Mouser on high quantities at least. So it should be a problem to source the SDRAM.

For the W9812G6KH you have to go for speed rating -5 or -6. Then it should work. However, no guarantee on that as I just shortly scanned over pinout, commands and AC characteristics. But you may want to provide feedback, once tested. If you go for the chip with speed rate -75, you may have to adjust clock rate (143MHz to 133MHz), tRC (63ns -> 65ns) and tRAS (42ns -> 45ns). Otherwise it might be a bit of luck whether it works with current firmware or not.

Best regards

gmiranda, 2024-09-01:
Hi borti,

Thanks a lot for replying. I was planning on avoiding Mouser and instead go to LCSC, but now I see that I'd have to use a lot of alternative parts.

That said, I'm still having some trouble sourcing a couple of components. The first one would be U7, 74LVC2G17DBV. The closest one I can find on either Mouser or DigiKey is 74LVC2G17DBV**R**. Is it the same thing?

I also have doubts regarding the flex pcb, I hope you don't mind me asking. Have you ever ordered from JLCPCB? I don't know what to select on **Gold fingers**. Options are _yes_/_no_ and then it asks me about the gold finger thickness which puts me at a loss.

Thanks a lot!

borti4938, 2024-09-02:
Not sure, if you are using the latest version. Last version has neither U7 nor the gold fingers.

borti4938, 2024-09-02:
These are the options I set on my last order for the flex pcb. Works well
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

gmiranda, 2024-09-02:
> Not sure, if you are using the latest version. Last version has no U7. For the flex, you have to select "yes" for gold fingers (pins at the end for the connector).
It looks like I wasn't, thanks!

> These are the options I set on my last order for the flex pcb. Works well !
Awesome borti, thanks a lot! It looks like I had the values miraculously right.

gmiranda, 2024-09-04:
I'm now going through the flex pcb BOM and I'm having a similar issue with U1 as I did with former U7. Searching for 74LVC1G17DBV returns quite 6 different part numbers with the closest ones being SN74LVC1G17DBVR and SN74LVC1G17DBVT. Which one should I order?

borti4938, 2024-09-07:
You can go with either one. "SN" is probably for Texas Instrument and "R"/"T" is just the packaging the device comes (reel or tube), which is not important at all. Take the cheaper version.

gmiranda, 2024-10-22:
Sorry to keep bothering you... Are the pads of the clamps D21 and D22 intended to be electrically connected? I mean that with the bare PCB there's connection between the north side (HDMI connector) and the south side (analog devices chip) pads:

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

This lead me to believe that I had botched the solder work of these diodes :facepalm:

Once again, thanks a lot!

gmiranda, 2024-11-03:
I guess the answer is yes. I just don't understand how these clamps work.

Closed 2024-11-03.

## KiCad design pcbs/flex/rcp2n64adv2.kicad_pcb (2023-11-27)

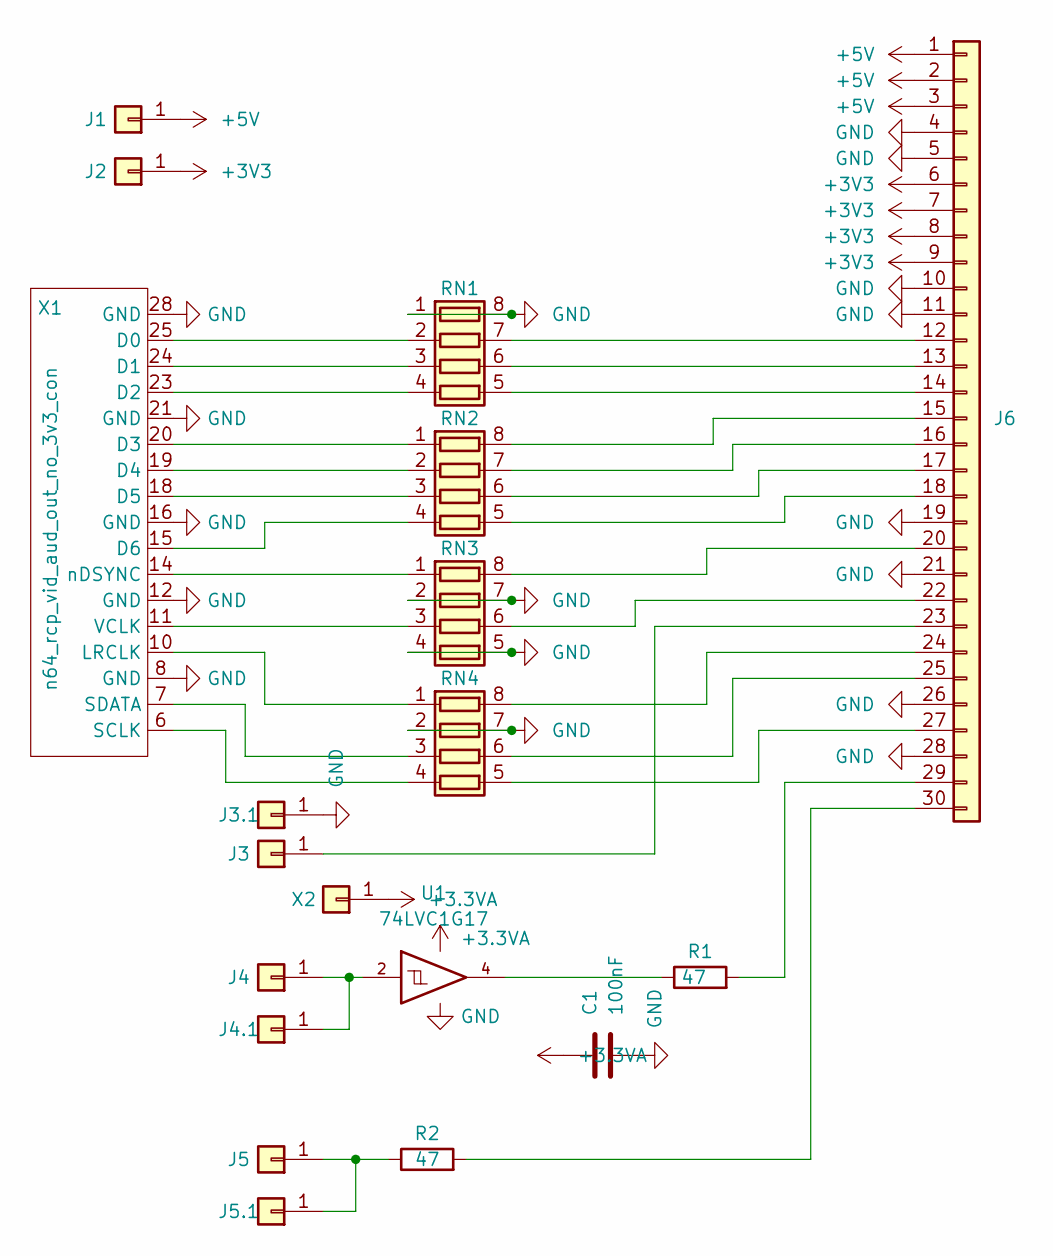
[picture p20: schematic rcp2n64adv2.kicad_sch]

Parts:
C1: 100nF; C_0603_1608Metric_Pad1.08x0.95mm_HandSolder
J1, J2: Conn_01x01; large
J3, J3.1, J4.1, J5.1: Conn_01x01; TestPoint_Pad_D1.5mm
J4, J5: Conn_01x01; medium
J6: Conn_01x30; EDGE-FH12-30S-0.5SH
R1, R2: 47; R_0603_1608Metric_Pad0.98x0.95mm_HandSolder
RN1, RN2, RN3, RN4: R_Pack04; R_Array_Convex_4x0603
U1: 74LVC1G17; TSOP-5_1.65x3.05mm_P0.95mm
X1: n64_rcp_vid_aud_out_no_3v3_con; Connector_RCP_Vi+Aud_Interface_no_3V3
X2: Conn_01x01; small

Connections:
+3.3VA: C1.1, U1.5 (VCC), X2.1
+3V3: J2.1, J6.6, J6.7, J6.8, J6.9
+5V: J1.1, J6.1, J6.2, J6.3
GND: C1.2, J3.1.1, J6.4, J6.5, J6.10, J6.11, J6.19, J6.21, J6.26, J6.28, RN1.1 (R1.1), RN1.8 (R1.2), RN3.2 (R2.1), RN3.4 (R4.1), RN3.5 (R4.2), RN3.7 (R2.2), RN4.2 (R2.1), RN4.7 (R2.2), U1.3 (GND), X1.8 (GND), X1.12 (GND), X1.16 (GND), X1.21 (GND), X1.28 (GND)
unnamed: J3.1, J6.23
unnamed: J4.1, J4.1.1, U1.2
unnamed: J5.1, J5.1.1, R2.1
unnamed: J6.12, RN1.7 (R2.2)
unnamed: J6.13, RN1.6 (R3.2)
unnamed: J6.14, RN1.5 (R4.2)
unnamed: J6.15, RN2.8 (R1.2)
unnamed: J6.16, RN2.7 (R2.2)
unnamed: J6.17, RN2.6 (R3.2)
unnamed: J6.18, RN2.5 (R4.2)
unnamed: J6.20, RN3.8 (R1.2)
unnamed: J6.22, RN3.6 (R3.2)
unnamed: J6.24, RN4.8 (R1.2)
unnamed: J6.25, RN4.6 (R3.2)
unnamed: J6.27, RN4.5 (R4.2)
unnamed: J6.29, R1.2
unnamed: J6.30, R2.2
unnamed: R1.1, U1.4
unnamed: RN1.2 (R2.1), X1.25 (D0)
unnamed: RN1.3 (R3.1), X1.24 (D1)
unnamed: RN1.4 (R4.1), X1.23 (D2)
unnamed: RN2.1 (R1.1), X1.20 (D3)
unnamed: RN2.2 (R2.1), X1.19 (D4)
unnamed: RN2.3 (R3.1), X1.18 (D5)
unnamed: RN2.4 (R4.1), X1.15 (D6)
unnamed: RN3.1 (R1.1), X1.14 (nDSYNC)
unnamed: RN3.3 (R3.1), X1.11 (VCLK)
unnamed: RN4.1 (R1.1), X1.10 (LRCLK)
unnamed: RN4.3 (R3.1), X1.7 (SDATA)
unnamed: RN4.4 (R4.1), X1.6 (SCLK)

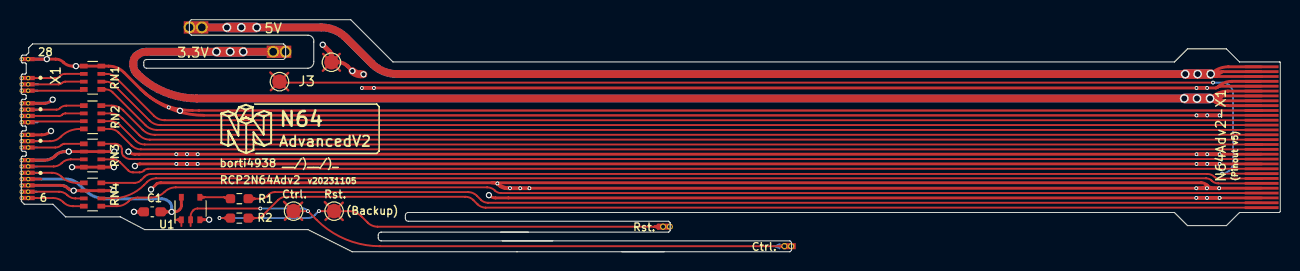
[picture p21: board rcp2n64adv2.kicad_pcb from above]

Board: 2 copper layers, 129.6 x 23.9 mm, 19 parts (1 on the bottom side), 34 nets.

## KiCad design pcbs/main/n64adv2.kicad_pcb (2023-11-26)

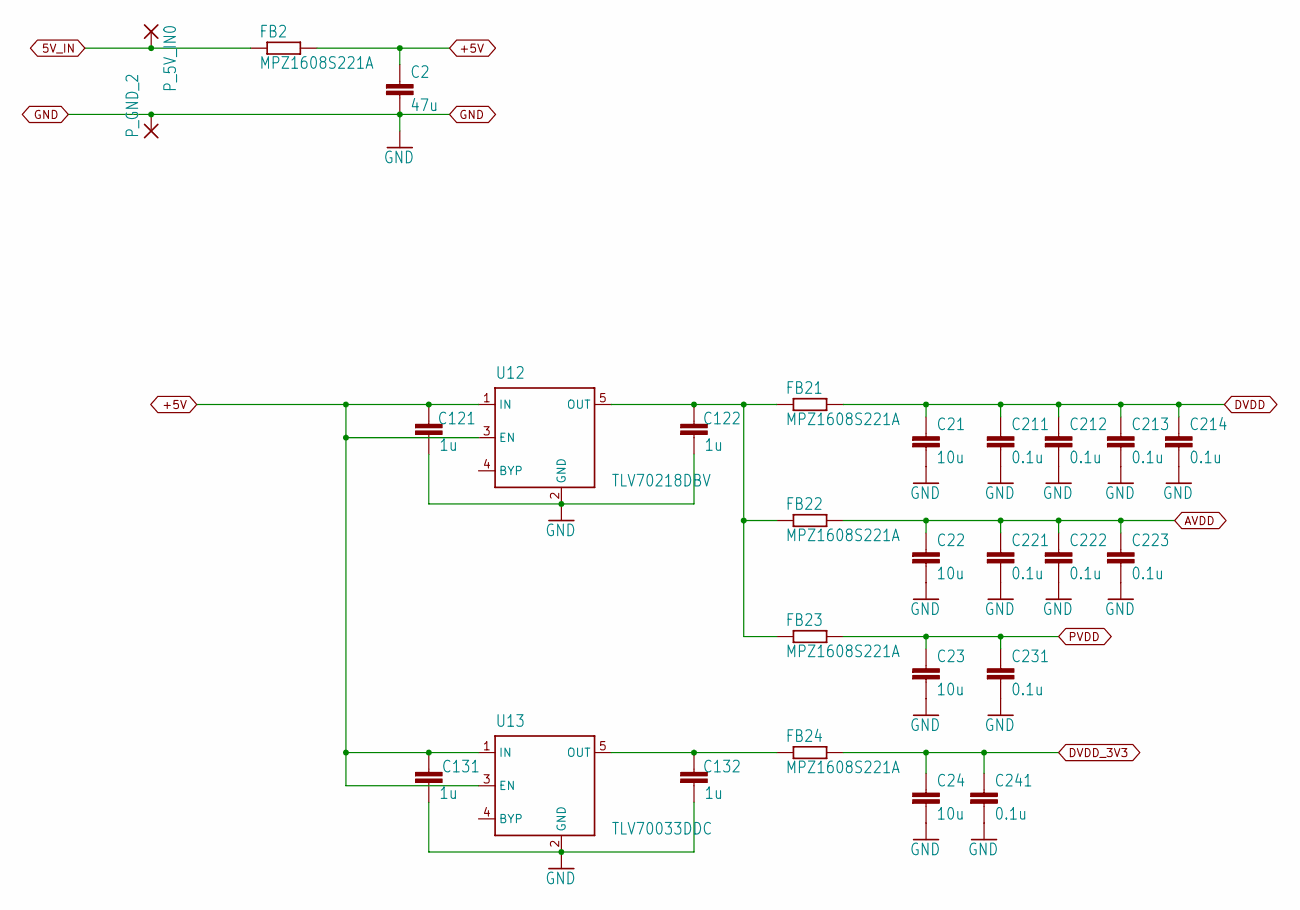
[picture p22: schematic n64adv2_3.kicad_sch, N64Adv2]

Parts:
C2: 47u; C0805
C21, C22, C23, C24: 10u; C0805
C121, C122, C131, C132: 1u; C0603
C211, C212, C213, C214, C221, C222, C223, C231, C241: 0.1u; C0603
FB2, FB21, FB22, FB23, FB24: MPZ1608S221A; R0603
P_5V_IN0: SMD2; SMD1,27-2,54
P_GND_2: SMD2; SMD1,27-2,54
U12: TLV70218DBV; SOT23-5
U13: TLV70033DDC; SOT23-5

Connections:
5V_IN: FB2.1, P_5V_IN0.1; also elsewhere on the board
+5V: C2.1, C121.1, C131.1, FB2.2, U12.1 (IN), U12.3 (EN), U13.1 (IN), U13.3 (EN); also elsewhere on the board
AVDD: C22.1, C221.1, C222.1, C223.1, FB22.2; also elsewhere on the board
DVDD: C21.1, C211.1, C212.1, C213.1, C214.1, FB21.2; also elsewhere on the board
DVDD_3V3: C24.1, C241.1, FB24.2; also elsewhere on the board
GND: C2.2, C21.2, C22.2, C23.2, C24.2, C121.2, C122.2, C131.2, C132.2, C211.2, C212.2, C213.2, C214.2, C221.2, C222.2, C223.2, C231.2, C241.2, P_GND_2.1, U12.2 (GND), U13.2 (GND); also elsewhere on the board
unnamed: C122.1, FB21.1, FB22.1, FB23.1, U12.5 (OUT)
unnamed: C132.1, FB24.1, U13.5 (OUT)
PVDD: C23.1, C231.1, FB23.2; also elsewhere on the board

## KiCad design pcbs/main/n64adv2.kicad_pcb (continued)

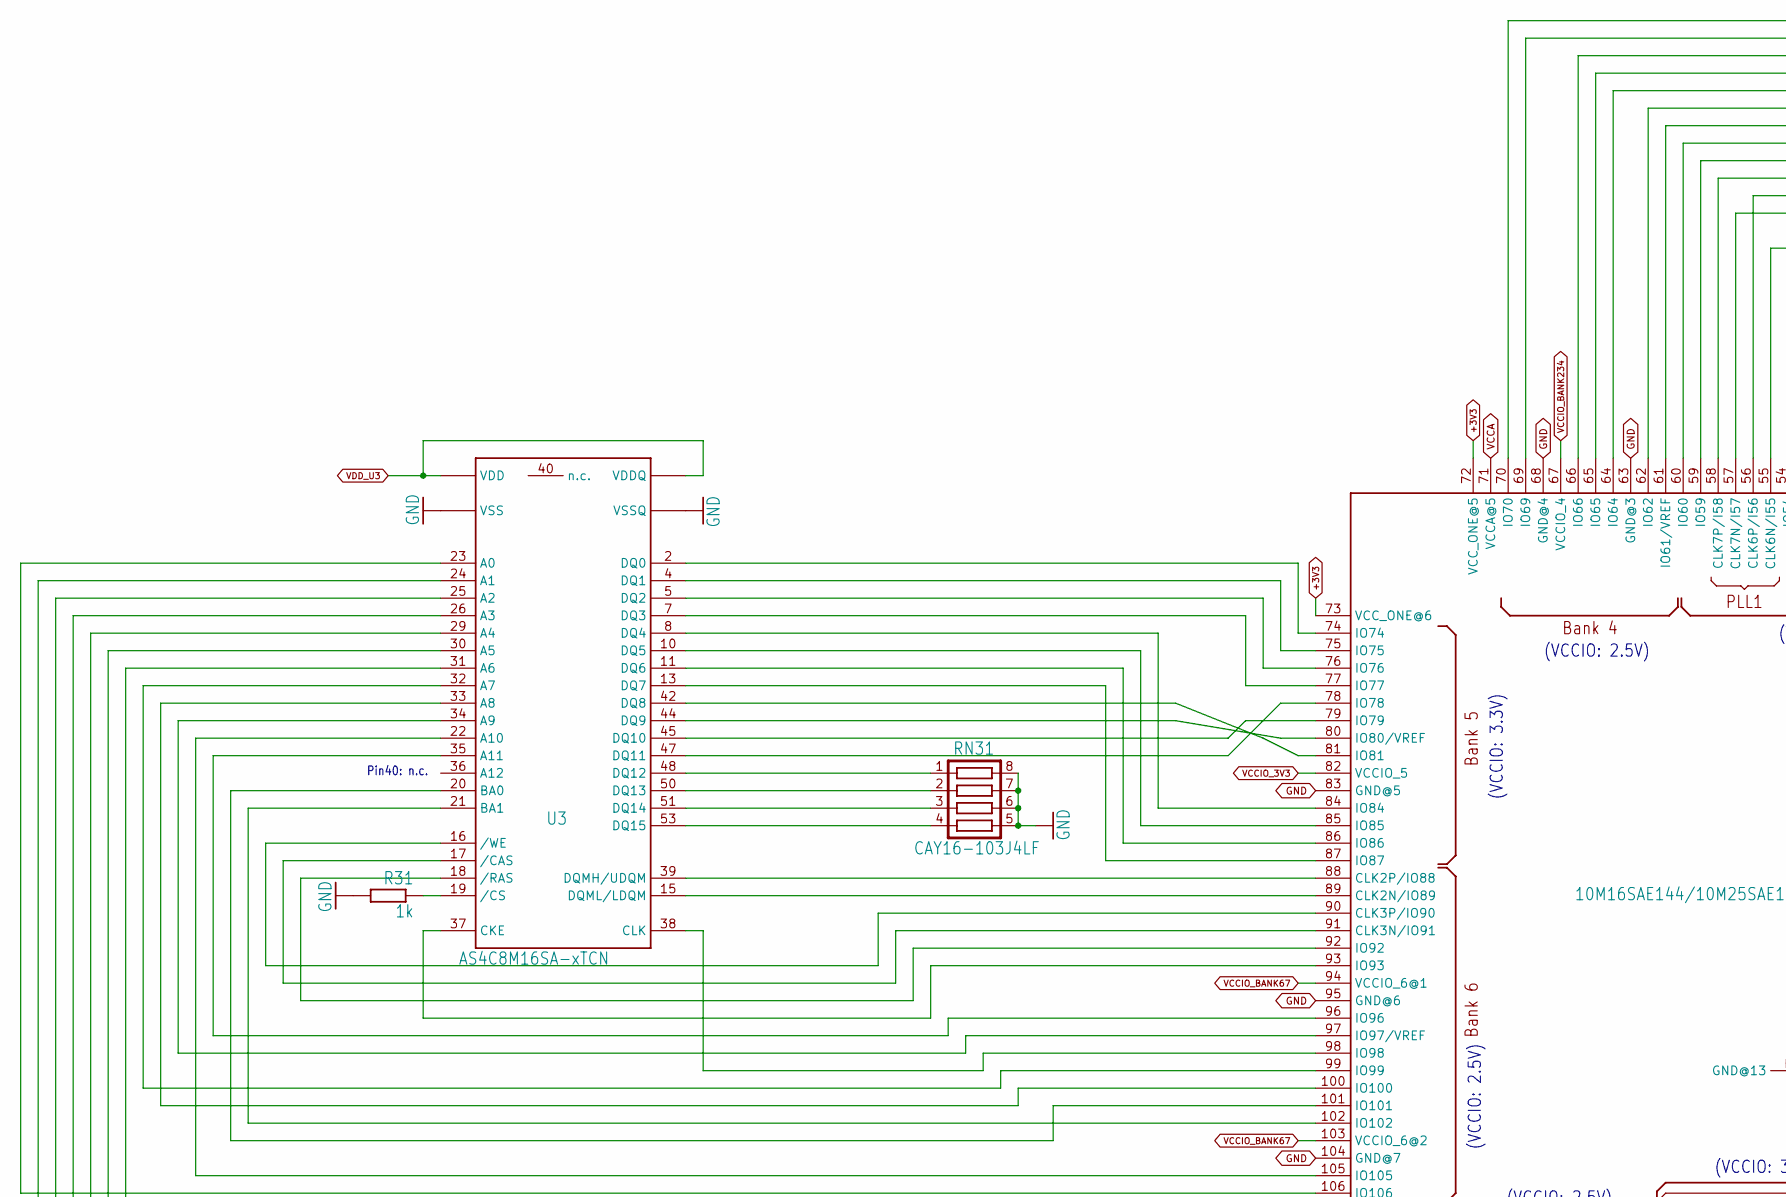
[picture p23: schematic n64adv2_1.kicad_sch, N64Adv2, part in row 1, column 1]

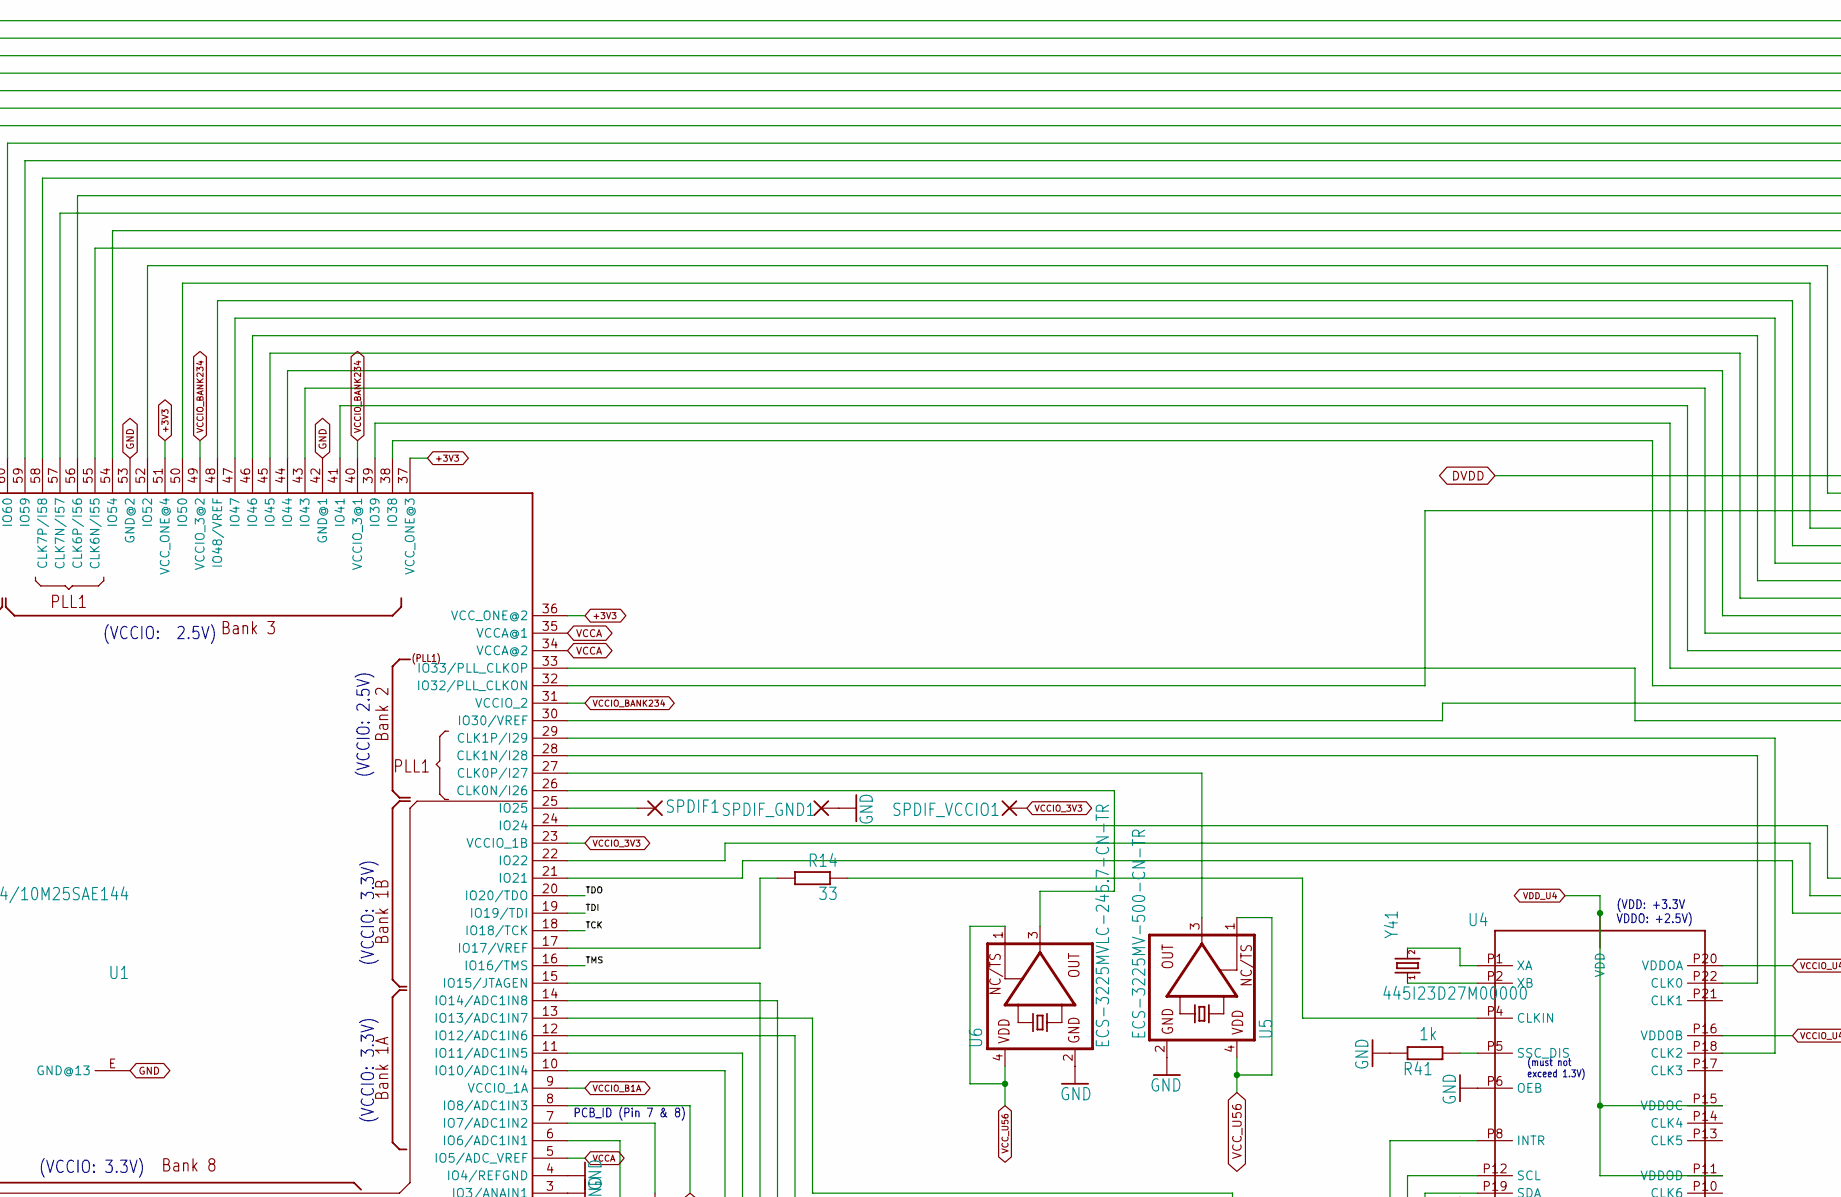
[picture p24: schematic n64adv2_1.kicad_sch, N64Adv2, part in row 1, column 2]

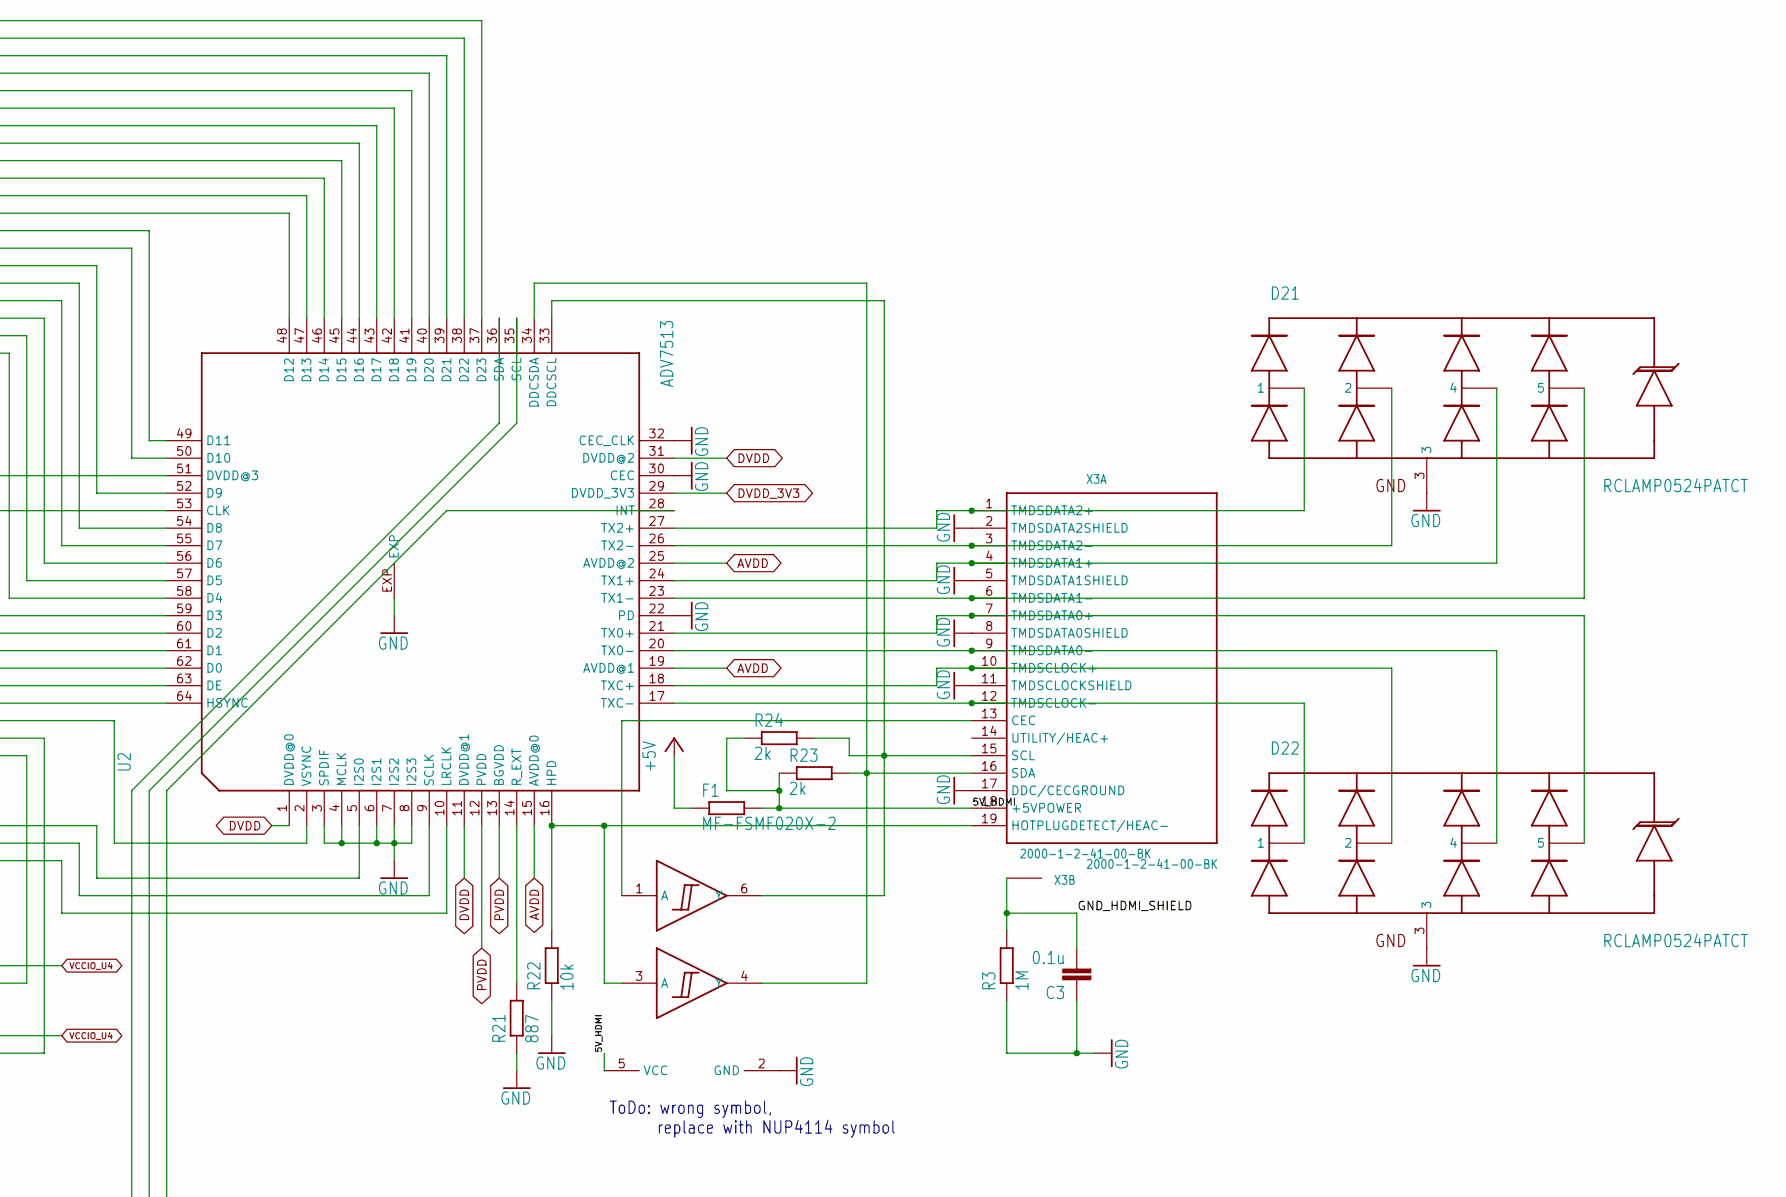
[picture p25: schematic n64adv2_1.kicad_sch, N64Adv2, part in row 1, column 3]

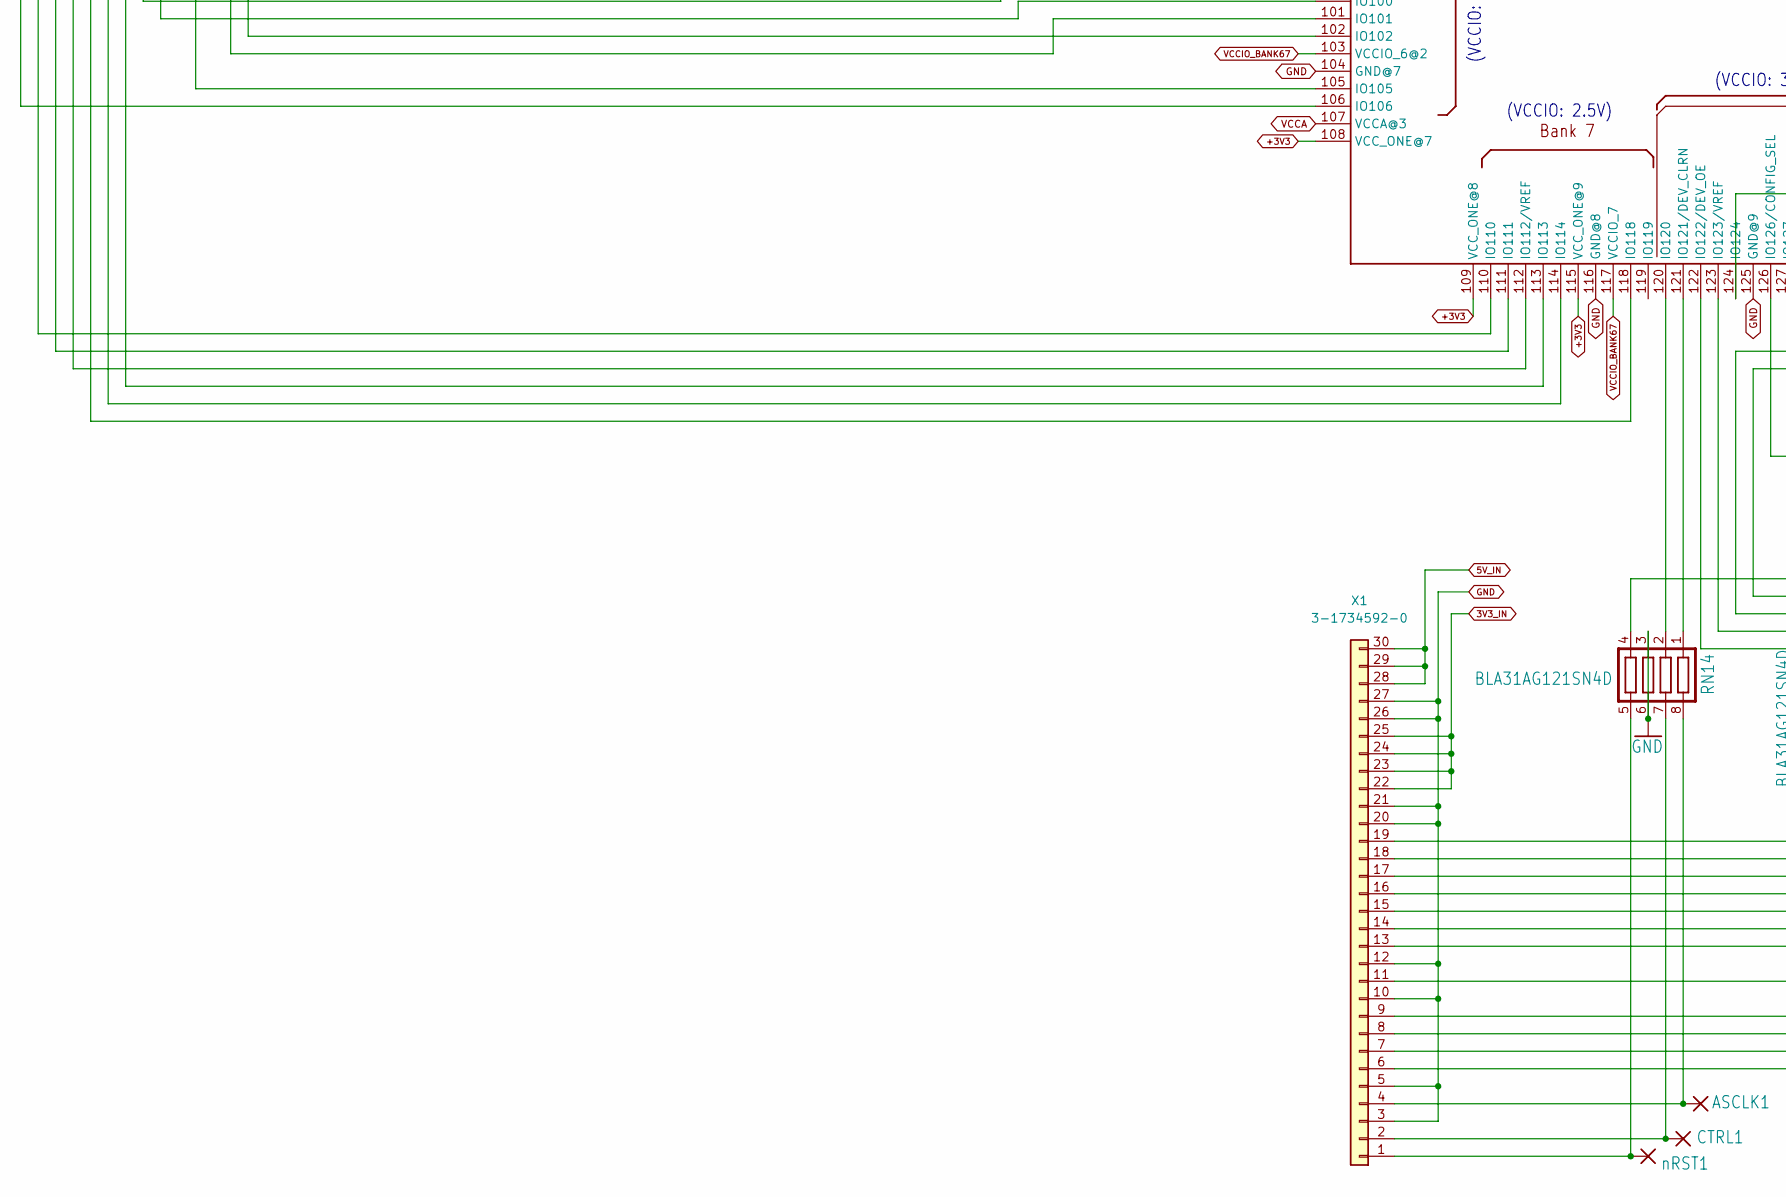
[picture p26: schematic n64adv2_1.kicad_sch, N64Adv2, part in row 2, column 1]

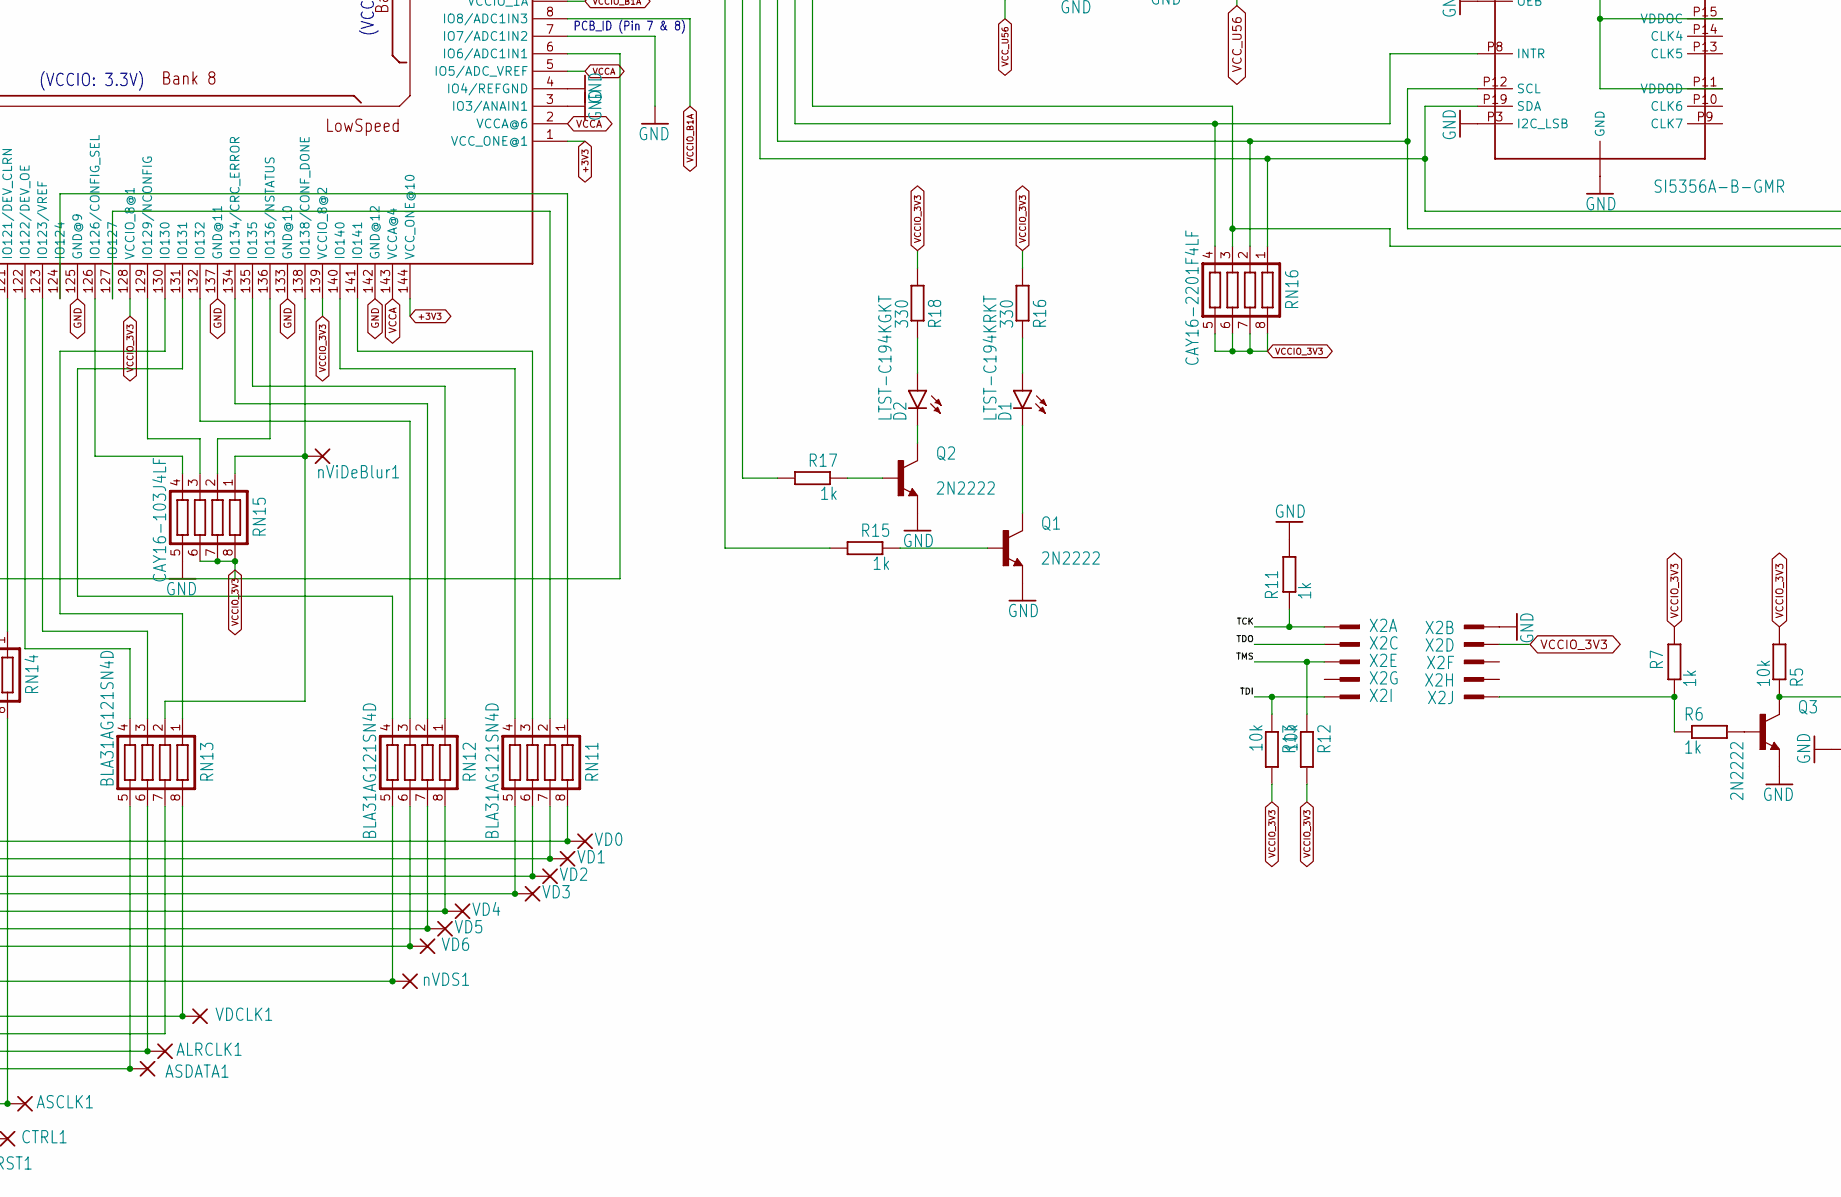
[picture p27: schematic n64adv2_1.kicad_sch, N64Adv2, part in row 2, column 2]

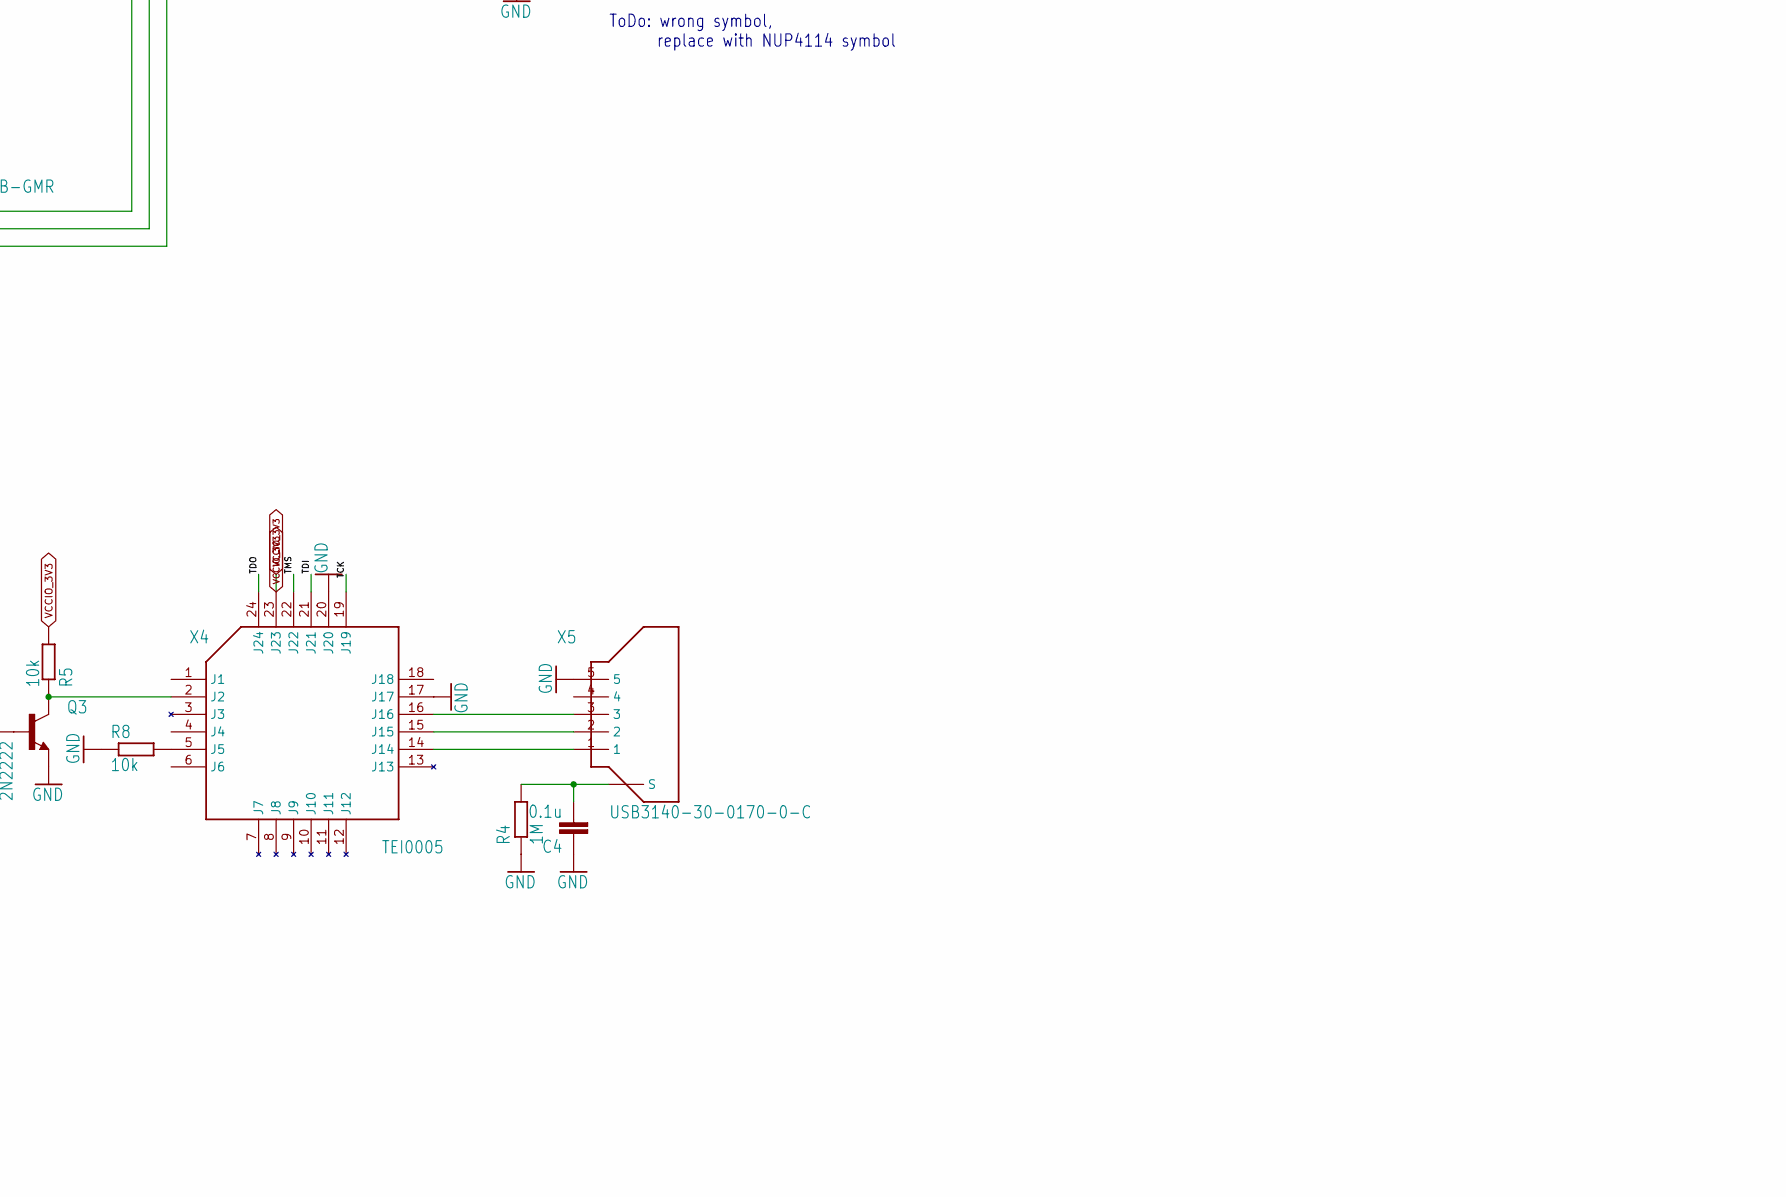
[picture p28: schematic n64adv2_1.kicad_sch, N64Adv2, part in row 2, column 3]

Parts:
ALRCLK1: SMD1; SMD0,8-1,6
ASCLK1: SMD1; SMD0,8-1,6
ASDATA1: SMD1; SMD0,8-1,6
C3, C4: 0.1u; C0603
CTRL1: SMD1; SMD0,8-1,6
D1: LTST-C194KRKT; CHIPLED_0805
D2: LTST-C194KGKT; CHIPLED_0805
D21, D22: RCLAMP0524PATCT; HDMI_RCLAMP
D23: NUP4114HMR6T1G; SOT-23-6
F1: MF-FSMF020X-2; R0603
Q1, Q2, Q3: 2N2222; SOT23
R3, R4: 1M; R0603
R5, R8, R12, R13, R22: 10k; R0603
R6, R7, R11, R15, R17, R31, R41: 1k; R0603
R14: 33; R0603
R16, R18: 330; R0603
R21: 887; R0603
R23, R24: 2k; R0603
RN11, RN12, RN13, RN14: BLA31AG121SN4D; CTS742C083
RN15, RN31: CAY16-103J4LF; CTS742C083
RN16: CAY16-2201F4LF; CTS742C083
SPDIF1: SMD1; SMD0,8-1,6
SPDIF_GND1: SMD1; SMD0,8-1,6
SPDIF_VCCIO1: SMD1; SMD0,8-1,6
U1: 10M16SAE144/10M25SAE144; EQFP144_2
U2: ADV7513; LQFP64_EP
U3: AS4C8M16SA-xTCN; TSOP-54
U4: SI5356A-B-GMR; QFN-24-DIY
U5: ECS-3225MV-500-CN-TR; 3.2X2.5_KXO-V96
U6: ECS-3225MVLC-245.7-CN-TR; 3.2X2.5_KXO-V96
VD0, VD1, VD2, VD3, VD4, VD5, VD6: SMD1; SMD0,8-1,6
VDCLK1: SMD1; SMD0,8-1,6
X1: 3-1734592-0; FH12-30S-0.5SH
X2: 3020-10-0300-00; PAK100_2500-10
X3: 2000-1-2-41-00-BK; hdmi_smd_shield_2000-1-2-41-00-BK
X4: TEI0005
X5: USB3140-30-0170-0-C; USB-MICRO-VERTICAL-DIY
Y41: 445I23D27M00000; 5.0X3.2_2
nRST1: SMD1; SMD0,8-1,6
nVDS1: SMD1; SMD0,8-1,6
nViDeBlur1: SMD1; SMD0,8-1,6

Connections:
3V3_IN: X1.22, X1.23, X1.24, X1.25; also elsewhere on the board
5V_IN: X1.28, X1.29, X1.30; also elsewhere on the board
+3V3: U1.1 (VCC_ONE@1), U1.36 (VCC_ONE@2), U1.37 (VCC_ONE@3), U1.51 (VCC_ONE@4), U1.72 (VCC_ONE@5), U1.73 (VCC_ONE@6), U1.108 (VCC_ONE@7), U1.109 (VCC_ONE@8), U1.115 (VCC_ONE@9), U1.144 (VCC_ONE@10); also elsewhere on the board
+5V: F1.1; also elsewhere on the board
/n64adv2_logic/5V_HDMI: D23.5 (VCC), F1.2, R23.1, R24.1, X3.18 (+5VPOWER)
/n64adv2_logic/GND_HDMI_SHIELD: C3.2, R3.2, X3.SHELL (SHIELD), X3.SHELL1 (SHIELD), X3.SHELL2 (SHIELD), X3.SHELL3 (SHIELD)
/n64adv2_logic/TCK: R11.1, U1.18 (IO18/TCK), X2.1 (KL), X4.19 (J19)
/n64adv2_logic/TDI: R13.1, U1.19 (IO19/TDI), X2.9 (KL), X4.21 (J21)
/n64adv2_logic/TDO: U1.20 (IO20/TDO), X2.3 (KL), X4.24 (J24)
/n64adv2_logic/TMS: R12.1, U1.16 (IO16/TMS), X2.5 (KL), X4.22 (J22)
AVDD: U2.15 (AVDD@0), U2.19 (AVDD@1), U2.25 (AVDD@2); also elsewhere on the board
DVDD: U2.1 (DVDD@0), U2.11 (DVDD@1), U2.31 (DVDD@2), U2.51 (DVDD@3); also elsewhere on the board
DVDD_3V3: U2.29 (DVDD_3V3); also elsewhere on the board
GND: C3.1, C4.1, D21.3, D22.3, D23.2 (GND), Q1.2 (E), Q2.2 (E), Q3.2 (E), R3.1, R4.1, R8.1, R11.2, R21.1, R22.1, R31.2, R41.2, RN14.3, RN14.6, RN15.5, RN31.5, RN31.6, RN31.7, RN31.8, SPDIF_GND1.P$1, U1.3 (IO3/ANAIN1), U1.4 (IO4/REFGND), U1.7 (IO7/ADC1IN2), U1.42 (GND@1), U1.53 (GND@2), U1.63 (GND@3), U1.68 (GND@4), U1.83 (GND@5), U1.95 (GND@6), U1.104 (GND@7), U1.116 (GND@8), U1.125 (GND@9), U1.133 (GND@10), U1.137 (GND@11), U1.142 (GND@12), U1.E (GND@13), U2.3 (SPDIF), U2.4 (MCLK), U2.6 (I2S1), U2.7 (I2S2), U2.8 (I2S3), U2.22 (PD), U2.30 (CEC), U2.32 (CEC_CLK), U2.EXP, U3.6 (VSSQ), U3.12 (VSSQ), U3.28 (VSS), U3.41 (VSS), U3.46 (VSSQ), U3.52 (VSSQ), U3.54 (VSS), U4.EXP (GND), U4.P3 (I2C_LSB), U4.P6 (OEB), U4.P23 (GND), U5.2 (GND), U6.2 (GND), X1.3, X1.5, X1.10, X1.12, X1.20, X1.21, X1.26, X1.27, X2.2 (KL), X3.2 (TMDSDATA2SHIELD), X3.5 (TMDSDATA1SHIELD), X3.8 (TMDSDATA0SHIELD), X3.11 (TMDSCLOCKSHIELD), X3.17 (DDC/CECGROUND), X4.17 (J17), X4.20 (J20), X5.5; also elsewhere on the board
unnamed: ALRCLK1.P$1, RN13.6, X1.7
unnamed: ASCLK1.P$1, RN14.8, X1.4
unnamed: ASDATA1.P$1, RN13.5, X1.6
unnamed: C4.2, R4.2, X5.6 (S), X5.7 (S)
unnamed: CTRL1.P$1, RN14.7, X1.2
unnamed: D1.A, R16.1
unnamed: D1.C, Q1.3 (C)
unnamed: D2.A, R18.1
unnamed: D2.C, Q2.3 (C)
unnamed: D21.1, D21.10 (1), U2.27 (TX2+), X3.1 (TMDSDATA2+)
unnamed: D21.2, D21.9 (2), U2.26 (TX2-), X3.3 (TMDSDATA2-)
unnamed: D21.4, D21.7 (4), U2.24 (TX1+), X3.4 (TMDSDATA1+)
unnamed: D21.5, D21.6 (5), U2.23 (TX1-), X3.6 (TMDSDATA1-)
unnamed: D22.1, D22.10 (1), U2.17 (TXC-), X3.12 (TMDSCLOCK-)
unnamed: D22.2, D22.9 (2), U2.18 (TXC+), X3.10 (TMDSCLOCK+)
unnamed: D22.4, D22.7 (4), U2.20 (TX0-), X3.9 (TMDSDATA0-)
unnamed: D22.5, D22.6 (5), U2.21 (TX0+), X3.7 (TMDSDATA0+)
unnamed: D23.1 (A), X3.13 (CEC)
unnamed: D23.3 (A), R22.2, U2.16 (HPD), X3.19 (HOTPLUGDETECT/HEAC-)
unnamed: D23.4 (Y), R23.2, U2.34 (DDCSDA), X3.16 (SDA)
unnamed: D23.6 (Y), R24.2, U2.33 (DDCSCL), X3.15 (SCL)
unnamed: Q1.1 (B), R15.1
unnamed: Q2.1 (B), R17.1
unnamed: Q3.1 (B), R6.2
unnamed: Q3.3 (C), R5.1, X4.2 (J2)
unnamed: R6.1, R7.1, X2.10 (KL)
unnamed: R8.2, X4.5 (J5)
unnamed: R14.1, U4.P4 (CLKIN)
unnamed: R14.2, U1.17 (IO17/VREF)
unnamed: R15.2, U1.10 (IO10/ADC1IN4)
unnamed: R17.2, U1.11 (IO11/ADC1IN5)
unnamed: R21.2, U2.14 (R_EXT)
unnamed: R31.1, U3.19 (/CS)
unnamed: R41.1, U4.P5 (SSC_DIS)
unnamed: RN11.1, U1.124 (IO124)
unnamed: RN11.2, U1.127 (IO127)
unnamed: RN11.3, U1.141 (IO141)
unnamed: RN11.4, U1.140 (IO140)
unnamed: RN11.5, VD3.P$1, X1.16
unnamed: RN11.6, VD2.P$1, X1.17
unnamed: RN11.7, VD1.P$1, X1.18
unnamed: RN11.8, VD0.P$1, X1.19
unnamed: RN12.1, U1.135 (IO135)
unnamed: RN12.2, U1.134 (IO134/CRC_ERROR)
unnamed: RN12.3, U1.132 (IO132)
unnamed: RN12.4, U1.131 (IO131)
unnamed: RN12.5, X1.11, nVDS1.P$1
unnamed: RN12.6, VD6.P$1, X1.13
unnamed: RN12.7, VD5.P$1, X1.14
unnamed: RN12.8, VD4.P$1, X1.15
unnamed: RN13.1, U1.130 (IO130)
unnamed: RN13.2, RN15.1, U1.138 (IO138/CONF_DONE), nViDeBlur1.P$1
unnamed: RN13.3, U1.123 (IO123/VREF)
unnamed: RN13.4, U1.122 (IO122/DEV_OE)
unnamed: RN13.7, X1.8
unnamed: RN13.8, VDCLK1.P$1, X1.9
unnamed: RN14.1, U1.121 (IO121/DEV_CLRN)
unnamed: RN14.2, U1.120 (IO120)
unnamed: RN14.4, U1.6 (IO6/ADC1IN1)
unnamed: RN14.5, X1.1, nRST1.P$1
unnamed: RN15.2, U1.136 (IO136/NSTATUS)
unnamed: RN15.3, U1.129 (IO129/NCONFIG)
unnamed: RN15.4, U1.126 (IO126/CONFIG_SEL)
unnamed: RN16.1, U1.15 (IO15/JTAGEN), U2.36 (SDA), U4.P19 (SDA)
unnamed: RN16.2, U1.14 (IO14/ADC1IN8), U2.35 (SCL), U4.P12 (SCL)
unnamed: RN16.3, U1.13 (IO13/ADC1IN7), U2.28 (INT)
unnamed: RN16.4, U1.12 (IO12/ADC1IN6), U4.P8 (INTR)
unnamed: RN31.1, U3.48 (DQ12)
unnamed: RN31.2, U3.50 (DQ13)
unnamed: RN31.3, U3.51 (DQ14)
unnamed: RN31.4, U3.53 (DQ15)
unnamed: SPDIF1.P$1, U1.25 (IO25)
unnamed: U1.21 (IO21), U2.10 (LRCLK)
unnamed: U1.22 (IO22), U2.9 (SCLK)
unnamed: U1.24 (IO24), U2.5 (I2S0)
unnamed: U1.26 (CLK0N/I26), U6.3 (OUT)
unnamed: U1.27 (CLK0P/I27), U5.3 (OUT)
unnamed: U1.28 (CLK1N/I28), U4.P22 (CLK0)
unnamed: U1.29 (CLK1P/I29), U4.P18 (CLK2)
unnamed: U1.30 (IO30/VREF), U2.64 (HSYNC)
unnamed: U1.32 (IO32/PLL_CLKON), U2.53 (CLK)
unnamed: U1.33 (IO33/PLL_CLKOP), U2.2 (VSYNC)
unnamed: U1.38 (IO38), U2.63 (DE)
unnamed: U1.39 (IO39), U2.62 (D0)
unnamed: U1.41 (IO41), U2.61 (D1)
unnamed: U1.43 (IO43), U2.60 (D2)
unnamed: U1.44 (IO44), U2.59 (D3)
unnamed: U1.45 (IO45), U2.58 (D4)
unnamed: U1.46 (IO46), U2.57 (D5)
unnamed: U1.47 (IO47), U2.56 (D6)
unnamed: U1.48 (IO48/VREF), U2.55 (D7)
unnamed: U1.50 (IO50), U2.54 (D8)
unnamed: U1.52 (IO52), U2.52 (D9)
unnamed: U1.54 (IO54), U2.49 (D11)
unnamed: U1.55 (CLK6N/I55), U2.50 (D10)
unnamed: U1.56 (CLK6P/I56), U2.47 (D13)
unnamed: U1.57 (CLK7N/I57), U2.48 (D12)
unnamed: U1.58 (CLK7P/I58), U2.46 (D14)
unnamed: U1.59 (IO59), U2.45 (D15)
unnamed: U1.60 (IO60), U2.44 (D16)
unnamed: U1.61 (IO61/VREF), U2.43 (D17)
unnamed: U1.62 (IO62), U2.42 (D18)
unnamed: U1.64 (IO64), U2.41 (D19)
unnamed: U1.65 (IO65), U2.40 (D20)
unnamed: U1.66 (IO66), U2.39 (D21)
unnamed: U1.69 (IO69), U2.38 (D22)
unnamed: U1.70 (IO70), U2.37 (D23)
unnamed: U1.74 (IO74), U3.2 (DQ0)
unnamed: U1.75 (IO75), U3.4 (DQ1)
unnamed: U1.76 (IO76), U3.5 (DQ2)
unnamed: U1.77 (IO77), U3.7 (DQ3)
unnamed: U1.78 (IO78), U3.47 (DQ11)
unnamed: U1.79 (IO79), U3.45 (DQ10)
unnamed: U1.80 (IO80/VREF), U3.44 (DQ9)
unnamed: U1.81 (IO81), U3.42 (DQ8)
unnamed: U1.84 (IO84), U3.8 (DQ4)
unnamed: U1.85 (IO85), U3.10 (DQ5)
unnamed: U1.86 (IO86), U3.11 (DQ6)
unnamed: U1.87 (IO87), U3.13 (DQ7)
unnamed: U1.88 (CLK2P/IO88), U3.39 (DQMH/UDQM)
unnamed: U1.89 (CLK2N/IO89), U3.15 (DQML/LDQM)
unnamed: U1.90 (CLK3P/IO90), U3.16 (/WE)
unnamed: U1.91 (CLK3N/IO91), U3.17 (/CAS)
unnamed: U1.92 (IO92), U3.18 (/RAS)
unnamed: U1.93 (IO93), U3.37 (CKE)
unnamed: U1.96 (IO96), U3.35 (A11)
unnamed: U1.97 (IO97/VREF), U3.34 (A9)
unnamed: U1.98 (IO98), U3.38 (CLK)
unnamed: U1.99 (IO99), U3.32 (A7)
unnamed: U1.100 (IO100), U3.33 (A8)
unnamed: U1.101 (IO101), U3.20 (BA0)
unnamed: U1.102 (IO102), U3.21 (BA1)
unnamed: U1.105 (IO105), U3.22 (A10)
unnamed: U1.106 (IO106), U3.23 (A0)
unnamed: U1.110 (IO110), U3.24 (A1)
unnamed: U1.111 (IO111), U3.25 (A2)
unnamed: U1.112 (IO112/VREF), U3.26 (A3)
unnamed: U1.113 (IO113), U3.31 (A6)
unnamed: U1.114 (IO114), U3.30 (A5)
unnamed: U1.118 (IO118), U3.29 (A4)
unnamed: U4.P1 (XA), Y41.2
unnamed: U4.P2 (XB), Y41.1
unnamed: X4.14 (J14), X5.1
unnamed: X4.15 (J15), X5.2
unnamed: X4.16 (J16), X5.3
PVDD: U2.12 (PVDD), U2.13 (BGVDD); also elsewhere on the board
VCCA: U1.2 (VCCA@6), U1.5 (IO5/ADC_VREF), U1.34 (VCCA@2), U1.35 (VCCA@1), U1.71 (VCCA@5), U1.107 (VCCA@3), U1.143 (VCCA@4); also elsewhere on the board
VCCIO_2V5: U1.31 (VCCIO_2), U1.40 (VCCIO_3@1), U1.49 (VCCIO_3@2), U1.67 (VCCIO_4); also elsewhere on the board
VCCIO_3V3: R5.2, R7.2, R12.2, R13.2, R16.2, R18.2, RN15.6, RN15.7, RN15.8, RN16.5, RN16.6, RN16.7, RN16.8, SPDIF_VCCIO1.P$1, U1.23 (VCCIO_1B), U1.82 (VCCIO_5), U1.128 (VCCIO_8@1), U1.139 (VCCIO_8@2), X2.4 (KL), X4.23 (J23); also elsewhere on the board
VCCIO_B1A: U1.8 (IO8/ADC1IN3), U1.9 (VCCIO_1A); also elsewhere on the board
VCCIO_BANK67: U1.94 (VCCIO_6@1), U1.103 (VCCIO_6@2), U1.117 (VCCIO_7); also elsewhere on the board
VCCIO_U4: U4.P16 (VDDOB), U4.P20 (VDDOA); also elsewhere on the board
VCC_U56: U5.1 (TS), U5.4 (VDD), U6.1 (TS), U6.4 (VDD); also elsewhere on the board
VDD_U3: U3.1 (VDD), U3.3 (VDDQ), U3.9 (VDDQ), U3.14 (VDD), U3.27 (VDD), U3.43 (VDDQ), U3.49 (VDDQ); also elsewhere on the board
VDD_U4: U4.P7 (VDD), U4.P11 (VDDOD), U4.P15 (VDDOC), U4.P24 (VDD); also elsewhere on the board

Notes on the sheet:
(VCCIO: 3.3V)
PCB_ID (Pin 7 & 8)
(VCCIO: 2.5V)
ToDo: wrong symbol, replace with NUP4114 symbol
(VDD: +3.3V VDDO: +2.5V)
Pin40: n.c.
(VCCIO: 2.5V)
(must not exceed 1.3V)

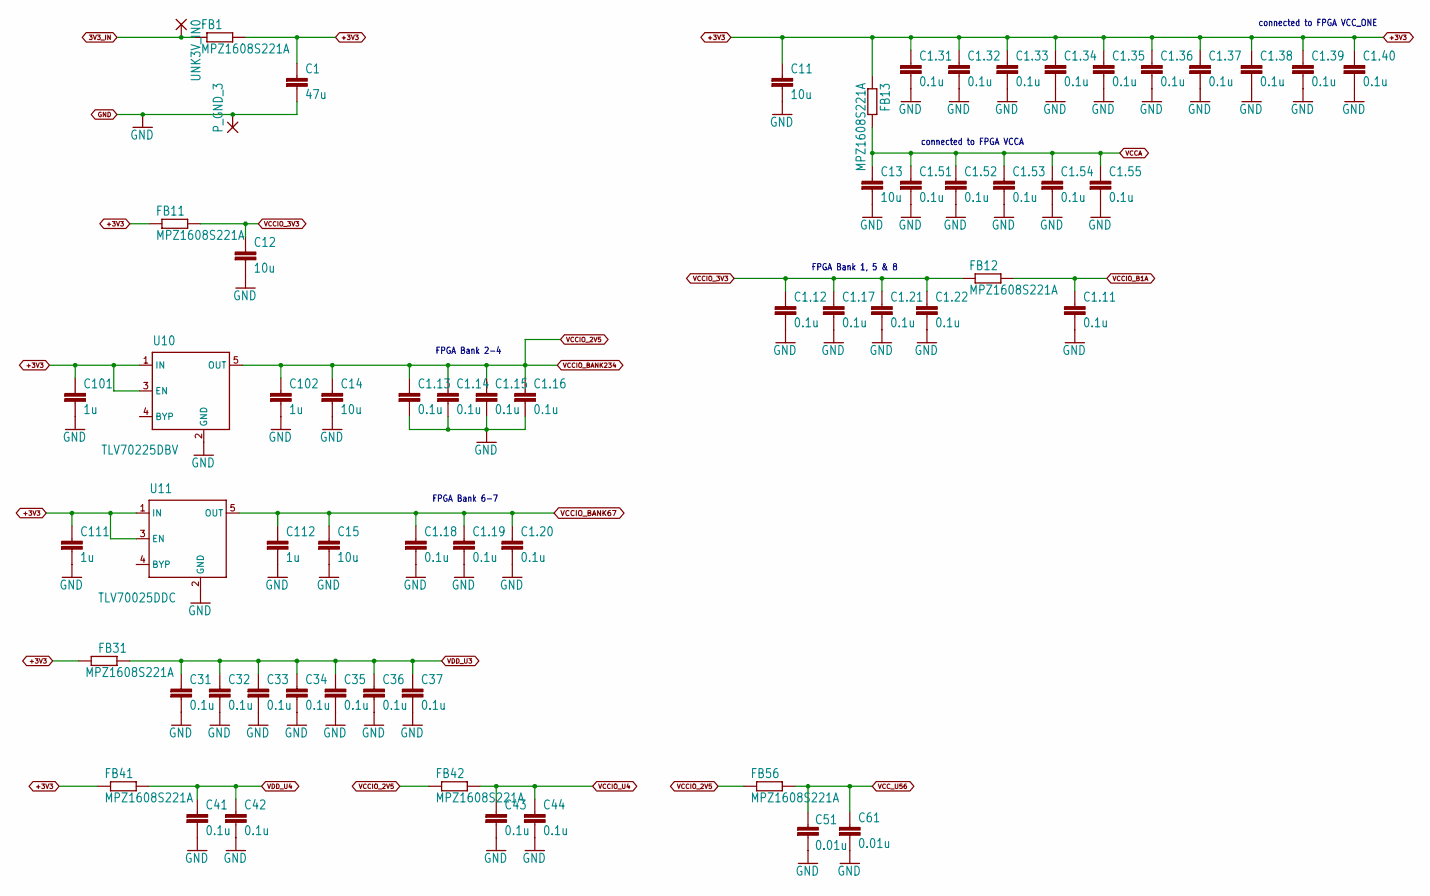
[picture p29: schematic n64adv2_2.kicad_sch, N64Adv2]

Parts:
C1: 47u; C0805
C1.11, C1.12, C1.13, C1.14, C1.15, C1.16, C1.17, C1.18, C1.19, C1.20, C1.21, C1.22, C1.31, C1.32, C1.33, C1.34, C1.35, C1.36, C1.37, C1.38, C1.39, C1.40, C1.51, C1.52, C1.53, C1.54, C1.55, C31, C32, C33, C34, C35, C36, C37, C41, C42, C43, C44: 0.1u; C0603
C11, C12, C13, C14, C15: 10u; C0805
C51, C61: 0.01u; C0603
C101, C102, C111, C112: 1u; C0603
FB1, FB11, FB12, FB13, FB31, FB41, FB42, FB56: MPZ1608S221A; R0603
P_GND_3: SMD2; SMD1,27-2,54
U10: TLV70225DBV; SOT23-5
U11: TLV70025DDC; SOT23-5
UNK3V_IN0: SMD2; SMD1,27-2,54

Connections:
3V3_IN: FB1.1, UNK3V_IN0.1; also elsewhere on the board
+3V3: C1.1, C1.31.1, C1.32.1, C1.33.1, C1.34.1, C1.35.1, C1.36.1, C1.37.1, C1.38.1, C1.39.1, C1.40.1, C11.1, C101.1, C111.1, FB1.2, FB11.1, FB13.1, FB31.1, FB41.1, U10.1 (IN), U10.3 (EN), U11.1 (IN), U11.3 (EN); also elsewhere on the board
GND: C1.2, C1.11.2, C1.12.2, C1.13.2, C1.14.2, C1.15.2, C1.16.2, C1.17.2, C1.18.2, C1.19.2, C1.20.2, C1.21.2, C1.22.2, C1.31.2, C1.32.2, C1.33.2, C1.34.2, C1.35.2, C1.36.2, C1.37.2, C1.38.2, C1.39.2, C1.40.2, C1.51.2, C1.52.2, C1.53.2, C1.54.2, C1.55.2, C11.2, C12.2, C13.2, C14.2, C15.2, C31.2, C32.2, C33.2, C34.2, C35.2, C36.2, C37.2, C41.2, C42.2, C43.2, C44.2, C51.2, C61.2, C101.2, C102.2, C111.2, C112.2, P_GND_3.1, U10.2 (GND), U11.2 (GND); also elsewhere on the board
VCCA: C1.51.1, C1.52.1, C1.53.1, C1.54.1, C1.55.1, C13.1, FB13.2; also elsewhere on the board
VCCIO_2V5: C1.13.1, C1.14.1, C1.15.1, C1.16.1, C14.1, C102.1, FB42.1, FB56.1, U10.5 (OUT); also elsewhere on the board
VCCIO_3V3: C1.12.1, C1.17.1, C1.21.1, C1.22.1, C12.1, FB11.2, FB12.1; also elsewhere on the board
VCCIO_B1A: C1.11.1, FB12.2; also elsewhere on the board
VCCIO_BANK67: C1.18.1, C1.19.1, C1.20.1, C15.1, C112.1, U11.5 (OUT); also elsewhere on the board
VCCIO_U4: C43.1, C44.1, FB42.2; also elsewhere on the board
VCC_U56: C51.1, C61.1, FB56.2; also elsewhere on the board
VDD_U3: C31.1, C32.1, C33.1, C34.1, C35.1, C36.1, C37.1, FB31.2; also elsewhere on the board
VDD_U4: C41.1, C42.1, FB41.2; also elsewhere on the board

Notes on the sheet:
connected to FPGA VCCA
connected to FPGA VCC_ONE
FPGA Bank 6-7
FPGA Bank 2-4
FPGA Bank 1, 5 & 8

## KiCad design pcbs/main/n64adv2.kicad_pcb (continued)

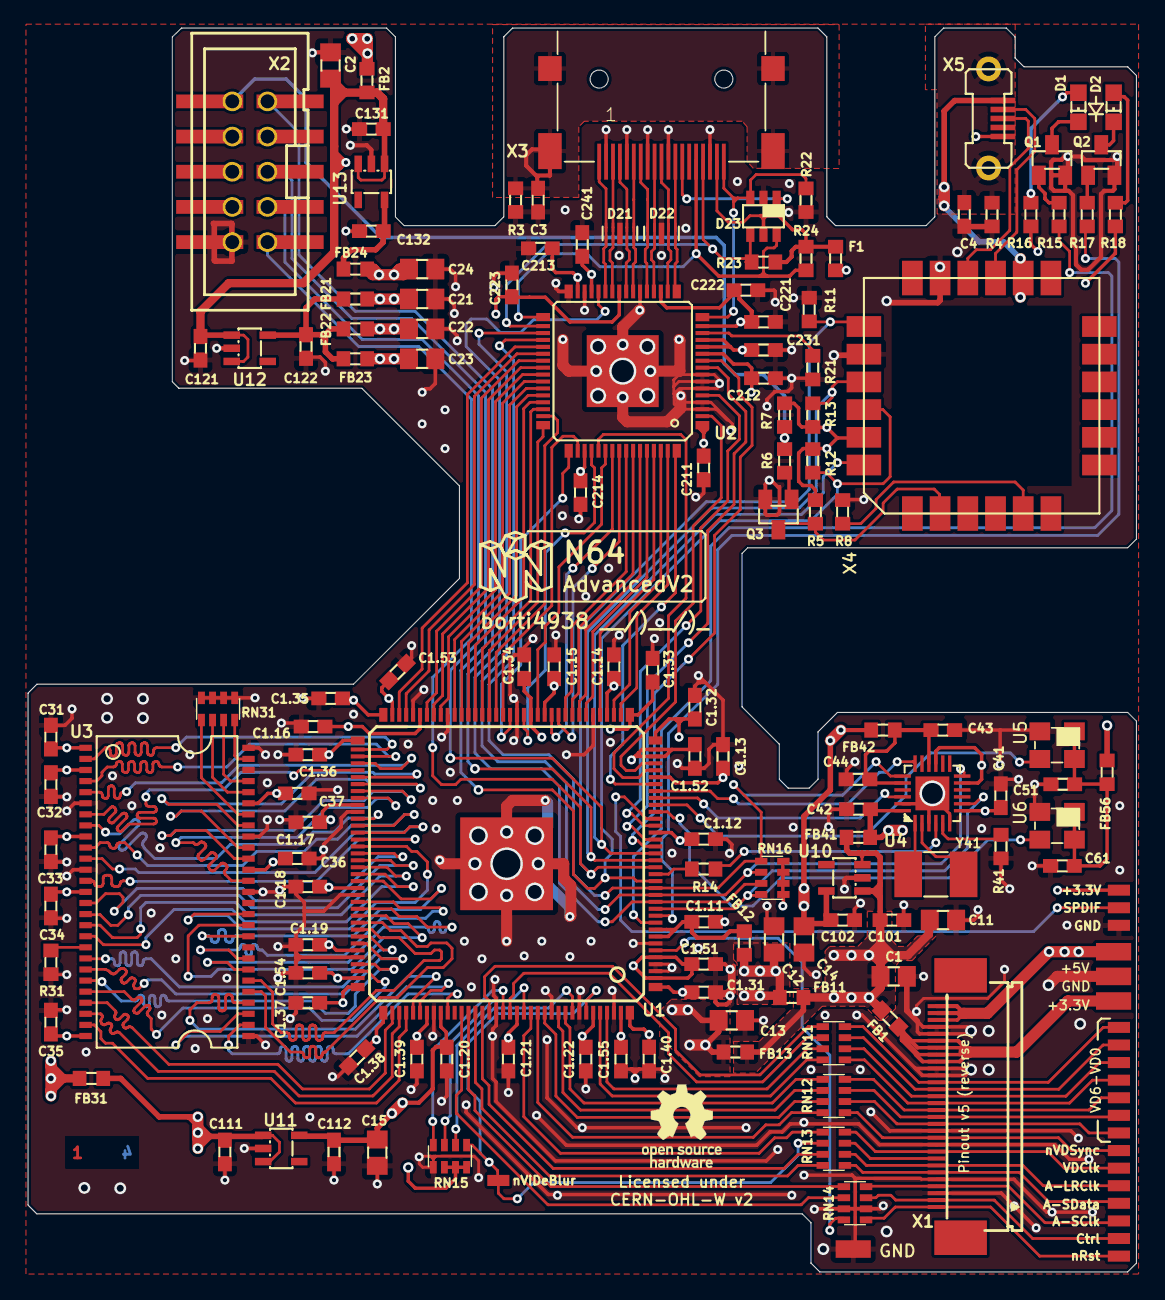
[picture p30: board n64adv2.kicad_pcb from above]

Board: 4 copper layers, 80.0 x 89.8 mm, 157 parts (0 on the bottom side), 171 nets.

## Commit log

2021-11-14 initial commit new repository
    [Filler_Round.stl, N64 Ad2.stl, N64ADV2_JTAG_Spacer v1.stl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]
2021-11-14 add full custom flex RCP to N64Adv2
    [RCP2N64Adv2.brd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]
2022-02-14 update JTAG spacer
    [N64ADV2_JTAG_Spacer v1.1.stl, N64ADV2_JTAG_Spacer v1.stl]
2022-04-18 huge update: - I know: commit is too large - port main PCB to KiCad - reorganize repo structure - add README
    [N64ADV2_JTAG_Spacer_v1p1.stl, N64Adv2_Half-Cut_v1p1.stl, N64Adv2_No-Cut_v1.stl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]
2022-07-22 update full flex: - redesign in KiCad - add trace for VI-DeBlur Feedback
    [rcp2n64adv2-B_Cu.gbr, rcp2n64adv2-B_Mask.gbr, rcp2n64adv2-B_Paste.gbr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]
2022-08-23 update flex PCB with minor changes, e.g. added a logo
    [rcp2fpc_v5.brd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]
2022-08-23 update main PCB with minor changes, e.g. ensure that solder mask bridges between 0.5mm pitched pads has min. 0.1mm thickness
    [n64adv2-B_Cu.gbr, n64adv2-B_Mask.gbr, n64adv2-B_Paste.gbr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]
2022-08-23 add PCB specs to README
2022-08-23 update common BOM
    [n64adv2_BOM.xlsx]
2022-09-05 update flex PCB: - add a feedback path for VI-Deblur - optimize implementation around U1 - add logo and license text to silkscreen
    [rcp2n64adv2-B_Cu.gbr, rcp2n64adv2-B_Mask.gbr, rcp2n64adv2-B_Paste.gbr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]
2022-09-05 update main PCB: - optimize some trace routing - optimize component selection/placing (e.g. HDMI port full SMD, JTAG as SMD alternative) - add license to silkscreen
    [n64adv2-B_Cu.gbr, n64adv2-B_Mask.gbr, n64adv2-B_Silkscreen.gbr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]
2022-09-05 update full BOM
    [n64adv2_BOM.xlsx]
2022-09-14 Main PCB update: - edge cuts: yet another update hopefully getting the perfect fit this time - hdmi connector position moved 0.5mm to the left - optimize mask for D21, D22, X3
    [n64adv2-B_Cu.gbr, n64adv2-B_Mask.gbr, n64adv2-B_Silkscreen.gbr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]
2022-10-09 tiny optimizations: - change HDMI footprint a bit (increase size of shield pads) - move HDMI port a bit further on the PCB - adapt copper pour on l2 a bit
    [n64adv2-B_Cu.gbr, n64adv2-B_Mask.gbr, n64adv2-B_Silkscreen.gbr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]
2022-11-06 reduce pad hole size at usb port and fix a gnd trace
2022-11-06 update gerbers
    [n64adv2-B_Cu.gbr, n64adv2-B_Mask.gbr, n64adv2-B_Silkscreen.gbr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]
2022-11-12 update 3d printed models for new HDMI port
    [N64Adv2_Half-Cut_v1p1.stl, N64Adv2_lift.stl]
2022-11-12 update names for 3D printed parts
    [N64Adv2_JTAG_Spacer.stl, N64Adv2_MultiOut_HalfCut.stl, N64Adv2_MultiOut_NoCut.stl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]
2022-11-20 give a bit mor space at the MultiOut stand-offs as earliest N64 models (PAL only???) seems to have thicker ones there
    [n64adv2-B_Cu.gbr, n64adv2-B_Mask.gbr, n64adv2-B_Silkscreen.gbr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]
2022-11-20 some BOM updates
    [n64adv2.kicad_sch, n64adv2_1.kicad_sch, n64adv2_BOM.xlsx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]
2022-12-01 fix edge cuts problem and rearrange some power supply lines near HDMI Tx
    [n64adv2-B_Cu.gbr, n64adv2-B_Mask.gbr, n64adv2-B_Silkscreen.gbr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]
2023-05-21 update part numbers for Y41,, RN11-14
    [n64adv2.kicad_sch, n64adv2_1.kicad_sch, n64adv2_BOM.xlsx]
2023-11-05 update main-pcb: - remove jumper which were left overs from prototype stages - remove some test points - add pads for SPDIF near DIY-IO-Pad area
    [n64adv2-B_Cu.gbr, n64adv2-B_Mask.gbr, n64adv2-B_Silkscreen.gbr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]
2023-11-05 Update flex-PCB: - move buffer IC to resistor array area of PCB (not on arms anymore) - add pads as backup if arms get ripped off
    [rcp2n64adv2-B_Cu.gbr, rcp2n64adv2-B_Mask.gbr, rcp2n64adv2-B_Paste.gbr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]
2023-11-26 Update main-PCB: - fixing solder mask - slightly move components a bit (USB port, JTAG, C2, ...)
    [n64adv2-B_Cu.gbr, n64adv2-B_Mask.gbr, n64adv2-B_Silkscreen.gbr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]
2023-11-26 Update BOM
    [n64adv2_BOM.xlsx]
2023-11-27 protect unconnected pad at U1 by small traces
    [rcp2n64adv2-B_Cu.gbr, rcp2n64adv2-B_Mask.gbr, rcp2n64adv2-B_Paste.gbr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]
2024-01-20 leave a note and BOM for the PicoDVI-N64_PCB project by dalogue1
    [n64adv2_flex_for_picodvi.xlsx]
2024-08-08 remove BOM for PicoDVI
    [n64adv2_flex_for_picodvi.xlsx]
2024-08-08 Adjust BOM a tiny bit
    [n64adv2_BOM.xlsx]

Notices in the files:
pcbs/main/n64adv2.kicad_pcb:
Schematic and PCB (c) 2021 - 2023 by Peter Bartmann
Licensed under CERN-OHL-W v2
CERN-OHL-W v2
